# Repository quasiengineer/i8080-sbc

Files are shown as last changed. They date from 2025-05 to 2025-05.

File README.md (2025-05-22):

# System board for Intel 8080
FPGA-based single board computer to run Intel 8080 CPU (up to 3.125Mhz)

## Board

Full schematics in [pdf format](./pcb/schematic.pdf)

Here is shown only main part of the board:
schematic

Archive with gerber files and drill locations could be found [here](./pcb/manufacturing.zip)

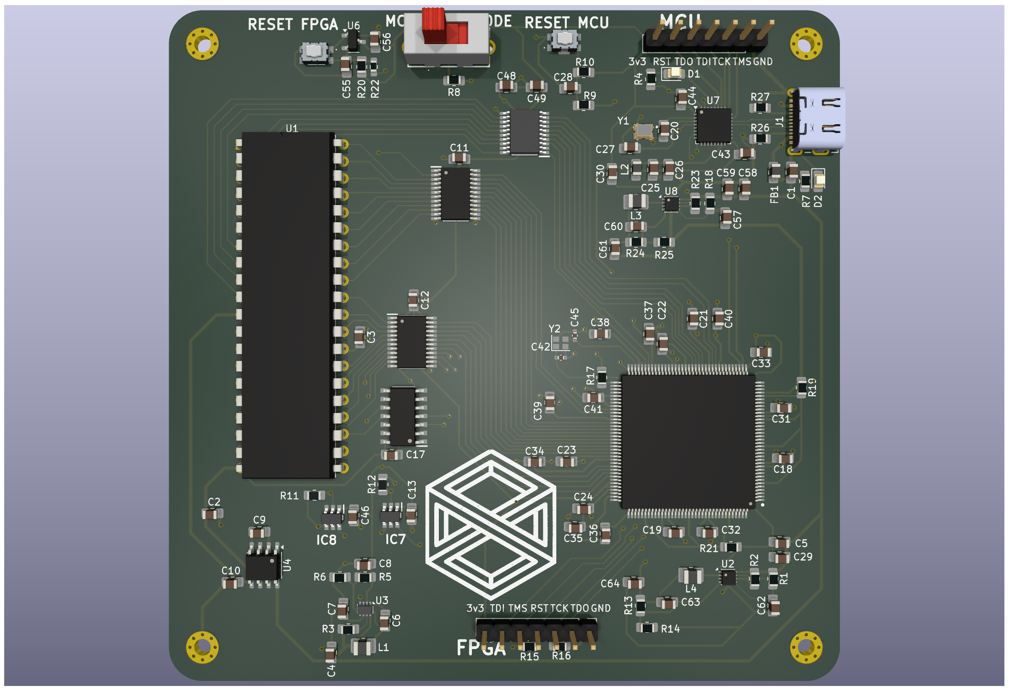
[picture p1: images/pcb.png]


Bill of material in [CSV format](./pcb/bom.csv)

|Reference |Value |Footprint |Mouser Part Number  |Qty|
|---|---|---|---|---|
|C1,C7,C25,C57,C62 |1u |Capacitor_SMD:C_0805_2012Metric_Pad1.18x1.45mm_HandSolder |187-CL21B105KAFNNNG |5  |
|C2,C3,C6,C11,C12,C13,C17,C18,C19,C21,C22,C23,<br>C24,C26,C28,C29,C31,C32,C33,C34,C35,C36,C37,<br>C38,C39,C40,C41,C43,C44,C46,C48,C49,C56,C58|100n |Capacitor_SMD:C_0805_2012Metric_Pad1.18x1.45mm_HandSolder |187-CL21B104KBCNNND |34 |
|C4,C30 |4u7,4u7, low-ESR |Capacitor_SMD:C_0805_2012Metric_Pad1.18x1.45mm_HandSolder |187-CL21A475KAQNNNE |2  |
|C5,C59,C61,C64 |22u |Capacitor_SMD:C_0805_2012Metric_Pad1.18x1.45mm_HandSolder |187-CL21A226MAYNNNE |4  |
|C8,C9,C10,C55 |10u,10u, low-ESR |Capacitor_SMD:C_0805_2012Metric_Pad1.18x1.45mm_HandSolder |187-CL21A106KAYNNNF |4  |
|C20,C27 |10p |Capacitor_SMD:C_0805_2012Metric_Pad1.18x1.45mm_HandSolder |710-885012007051 |2  |
|C42,C45 |10p |Capacitor_SMD:C_0402_1005Metric_Pad0.74x0.62mm_HandSolder |603-CC402JRNPO8BN100|2  |
|C60 |33p |Capacitor_SMD:C_0805_2012Metric_Pad1.18x1.45mm_HandSolder |710-885012007031 |1  |
|C63 |22p |Capacitor_SMD:C_0805_2012Metric_Pad1.18x1.45mm_HandSolder |710-885012007053 |1  |
|D1 |Red |LED_SMD:LED_0805_2012Metric_Pad1.15x1.40mm_HandSolder |710-150080RS75000 |1  |
|D2 |Green |LED_SMD:LED_0805_2012Metric_Pad1.15x1.40mm_HandSolder |710-150080GS75000 |1  |
|FB1 |Ferrite_Bead |Inductor_SMD:L_0805_2012Metric_Pad1.15x1.40mm_HandSolder  |652-MG2029-101Y |1  |
|H1,H2,H3,H4 |2.5mm |MountingHole:MountingHole_2.5mm_Pad_Via | |4  |
|IC1,IC2 |SN74LVC861APW |Project components:SOP65P640X120-24N |595-SN74LVC861APW |2  |
|IC5 |CD74HC243M96 |Project components:SOIC127P600X175-14N |595-CD74HC243M96 |1  |
|IC6 |M2GL005-TQG144I |Project components:QFP50P2200X2200X160-144N |494-M2GL005-TQG144I |1  |
|IC7,IC8 |UCC27511DBVR |SOT95P280X145-6N |595-UCC27511DBVR |2  |
|IC9 |TXS0108EPWRG4 |Project components:SOP65P640X120-20N |595-TXS0108EPWRG4 |1  |
|J1 |Type-C |Connector_USB:USB_C_Receptacle_JAE_DX07S016JA1R1500 |656-DX07S016JA1R1500|1  |
|J2,J4 |FPGA JTAG,MCU JTAG  |Connector_PinHeader_2.54mm:PinHeader_1x07_P2.54mm_Vertical|649-1012937990701BLF|2  |
|L1 |8u2, 800mA |Inductor_SMD:L_1008_2520Metric_Pad1.43x2.20mm_HandSolder  |81-DFE252012F-8R2MP2|1  |
|L2 |27n |Inductor_SMD:L_0805_2012Metric_Pad1.15x1.40mm_HandSolder  |652-CE201210-27NJ |1  |
|L3,L4 |0u68, 5.5A |Inductor_SMD:L_1008_2520Metric_Pad1.43x2.20mm_HandSolder  |652-SRP2512-R68M |2  |
|R1,R18 |10 |Resistor_SMD:R_0805_2012Metric_Pad1.20x1.40mm_HandSolder  |603-RT0805DRE0710RL |2  |
|R2,R13,R14,R23 |100k |Resistor_SMD:R_0805_2012Metric_Pad1.20x1.40mm_HandSolder  |603-RT0805DRE07100KL|4  |
|R3,R6 |30k |Resistor_SMD:R_0805_2012Metric_Pad1.20x1.40mm_HandSolder  |603-RT0805DRE0730KL |2  |
|R4 |4k7 |Resistor_SMD:R_0805_2012Metric_Pad1.20x1.40mm_HandSolder  |603-RT0805FRE134K7L |1  |
|R5 |330k |Resistor_SMD:R_0805_2012Metric_Pad1.20x1.40mm_HandSolder  |603-RT0805FRE07330KL|1  |
|R7 |2k2 |Resistor_SMD:R_0805_2012Metric_Pad1.20x1.40mm_HandSolder  |603-RT0805FRE072K2L |1  |
|R8,R10,R19,R20,R21 |10k |Resistor_SMD:R_0805_2012Metric_Pad1.20x1.40mm_HandSolder  |603-RT0805DRD0710KL |5  |
|R9,R11,R12 |220 |Resistor_SMD:R_0805_2012Metric_Pad1.20x1.40mm_HandSolder  |603-RT0805FRE07220RL|3  |
|R15,R16,R17 |1k |Resistor_SMD:R_0805_2012Metric_Pad1.20x1.40mm_HandSolder  |603-RT0805FRE071KL  |3  |
|R22 |50 |Resistor_SMD:R_0603_1608Metric_Pad0.98x0.95mm_HandSolder  |603-RT0603BRE0750RL |1  |
|R24 |158k |Resistor_SMD:R_0805_2012Metric_Pad1.20x1.40mm_HandSolder  |603-RT0805FRE07158KL|1  |
|R25 |34k8 |Resistor_SMD:R_0805_2012Metric_Pad1.20x1.40mm_HandSolder  |603-RT0805FRE0734K8L|1  |
|R26,R27 |5k1 |Resistor_SMD:R_0805_2012Metric_Pad1.20x1.40mm_HandSolder  |603-RT0805FRE075K1L |2  |
|SW1 |BOOT_MODE |Project components:SLW1215865AD |SLW-121586-5A-D |1  |
|SW2,SW3 |RESET_FPGA,RESET_MCU|Project components:435451019820 |710-435451019820 |2  |
|U1 |8080A |Package_DIP:DIP-40_W15.24mm |571-1-2199299-5 |1  |
|U2,U8 |LX7167ACLD-TR |Package_DFN_QFN:DFN-8-1EP_2x2mm_P0.5mm_EP0.8x1.6mm |494-LX7167ACLD-TR |2  |
|U3 |MP3438 |Package_TO_SOT_SMD:SOT-583-8 |946-MP3438GTL-P |1  |
|U4 |ICL7660 |Package_SO:SOIC-8_3.9x4.9mm_P1.27mm |968-ICL7660CBAZA-T  |1  |
|U6 |APX803-31SAG-7 |Package_TO_SOT_SMD:SOT-23-3 |621-APX803-31SAG-7  |1  |
|U7 |STM32G4A1KEUx |Package_DFN_QFN:QFN-32-1EP_5x5mm_P0.5mm_EP3.45x3.45mm |511-STM32G4A1KEU6 |1  |
|Y1 |16Mhz, CL=10p |Project components:XTAL_ECS-160-10-36-CKM-TR3 |520-160-10-36CKM-TR3|1  |
|Y2 |16Mhz |Crystal:Crystal_SMD_2016-4Pin_2.0x1.6mm |81-XRCGB16M000FXN02R|1  |

## MCU Firmware

There is compiled [hex file](./firmware/bin/i8080-sbc.hex) in repository, that could be flashed to PCB.

To flash you can use your favorite JTAG probe and software by your choice.
Or you can use default stm32 bootloader that supports uploading firmware via USB - just switch BOOT switch in direction to the USB connector.

I am using ft232r-based probe and OpenOCD, you can find my config [here](./openocd_stm32.cfg).

## FPGA bitstream

Again there is compiled [bitsream](./fpga/bin/i8080-sbc.dat).
So you could flash it by using either tool from vendor like FlashPro programmer or use same ft232 board and [DirectC-based tool](https://github.com/quasiengineer/microchip-jtag-flasher-ftdi).

## Software

To upload ROM/RAM image (i8080 has same memory space for ROM and RAM) you can type:

```sh
node index.js -port="COM1" -rom="hello_world" -verify
```

If all is good terminal should looks like that:

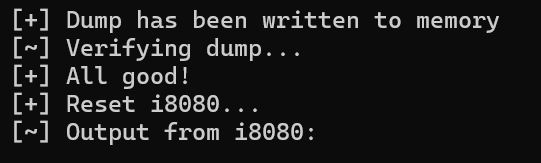
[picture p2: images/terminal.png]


Be aware that FPGA currently does not inform about i8080 HALT state, so controller software need to be terminated after end of i8080 program execution.

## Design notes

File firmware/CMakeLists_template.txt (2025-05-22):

#${templateWarning}
set(CMAKE_SYSTEM_NAME Generic)
set(CMAKE_SYSTEM_VERSION 1)
${cmakeRequiredVersion}
# specify cross-compilers and tools
set(CMAKE_C_COMPILER arm-none-eabi-gcc)
set(CMAKE_CXX_COMPILER arm-none-eabi-g++)
set(CMAKE_ASM_COMPILER  arm-none-eabi-gcc)
set(CMAKE_AR arm-none-eabi-ar)
set(CMAKE_OBJCOPY arm-none-eabi-objcopy)
set(CMAKE_OBJDUMP arm-none-eabi-objdump)
set(SIZE arm-none-eabi-size)
set(CMAKE_TRY_COMPILE_TARGET_TYPE STATIC_LIBRARY)

# project settings
project(${projectName} C CXX ASM)
set(CMAKE_CXX_STANDARD 17)
set(CMAKE_C_STANDARD 11)

#Uncomment for hardware floating point
#add_compile_definitions(ARM_MATH_CM4;ARM_MATH_MATRIX_CHECK;ARM_MATH_ROUNDING)
#add_compile_options(-mfloat-abi=hard -mfpu=fpv4-sp-d16)
#add_link_options(-mfloat-abi=hard -mfpu=fpv4-sp-d16)

#Uncomment for software floating point
#add_compile_options(-mfloat-abi=soft)

add_compile_options(-mcpu=${mcpu} -mthumb -mthumb-interwork)
add_compile_options(-ffunction-sections -fdata-sections -fno-common -fmessage-length=0)

# uncomment to mitigate c++17 absolute addresses warnings
#set(CMAKE_CXX_FLAGS "$${CMAKE_CXX_FLAGS} -Wno-register")

# Enable assembler files preprocessing
add_compile_options($<$<COMPILE_LANGUAGE:ASM>:-x$<SEMICOLON>assembler-with-cpp>)

if ("$${CMAKE_BUILD_TYPE}" STREQUAL "Release")
    message(STATUS "Maximum optimization for speed")
    add_compile_options(-Ofast)
elseif ("$${CMAKE_BUILD_TYPE}" STREQUAL "RelWithDebInfo")
    message(STATUS "Maximum optimization for speed, debug info included")
    add_compile_options(-Ofast -g)
elseif ("$${CMAKE_BUILD_TYPE}" STREQUAL "MinSizeRel")
    message(STATUS "Maximum optimization for size")
    add_compile_options(-Os)
else ()
    message(STATUS "Minimal optimization, debug info included")
    add_compile_options(-Og -g)
endif ()

include_directories(${includes} App)

add_definitions(${defines})

file(GLOB_RECURSE SOURCES ${sources} "App/*.*")

set(LINKER_SCRIPT $${CMAKE_SOURCE_DIR}/${linkerScript})

add_link_options(-Wl,-gc-sections,--print-memory-usage,-Map=$${PROJECT_BINARY_DIR}/$${PROJECT_NAME}.map)
add_link_options(-mcpu=${mcpu} -mthumb -mthumb-interwork)
add_link_options(-T $${LINKER_SCRIPT})

add_executable($${PROJECT_NAME}.elf $${SOURCES} $${LINKER_SCRIPT})

set(HEX_FILE $${PROJECT_BINARY_DIR}/$${PROJECT_NAME}.hex)
set(BIN_FILE $${PROJECT_BINARY_DIR}/$${PROJECT_NAME}.bin)

add_custom_command(TARGET $${PROJECT_NAME}.elf POST_BUILD
        COMMAND $${CMAKE_OBJCOPY} -Oihex $<TARGET_FILE:$${PROJECT_NAME}.elf> $${HEX_FILE}
        COMMAND $${CMAKE_OBJCOPY} -Obinary $<TARGET_FILE:$${PROJECT_NAME}.elf> $${BIN_FILE}
        COMMENT "Building $${HEX_FILE}
Building $${BIN_FILE}")

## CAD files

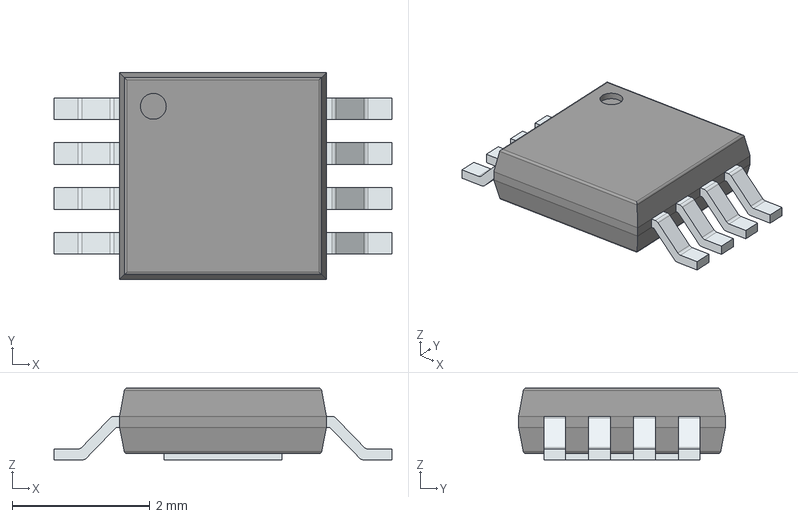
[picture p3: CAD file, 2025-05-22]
pcb/components/3d/2EDN7524RXTMA1.stp
4.90 x 3.00 x 1.04 mm
PinsArrayLR
ThermalPad

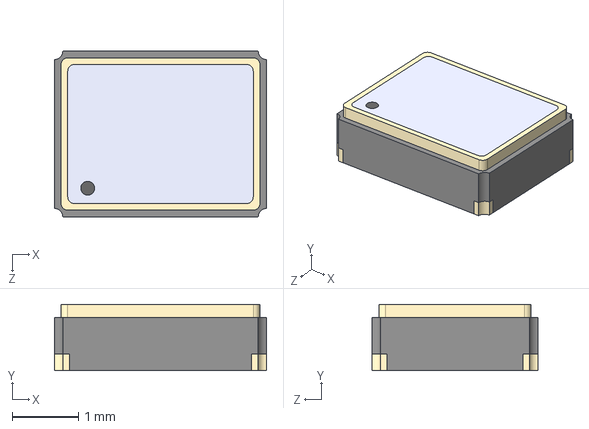
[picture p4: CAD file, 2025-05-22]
pcb/components/3d/ECS-2333-100-BN-TR.step
3.20 x 1.00 x 2.50 mm

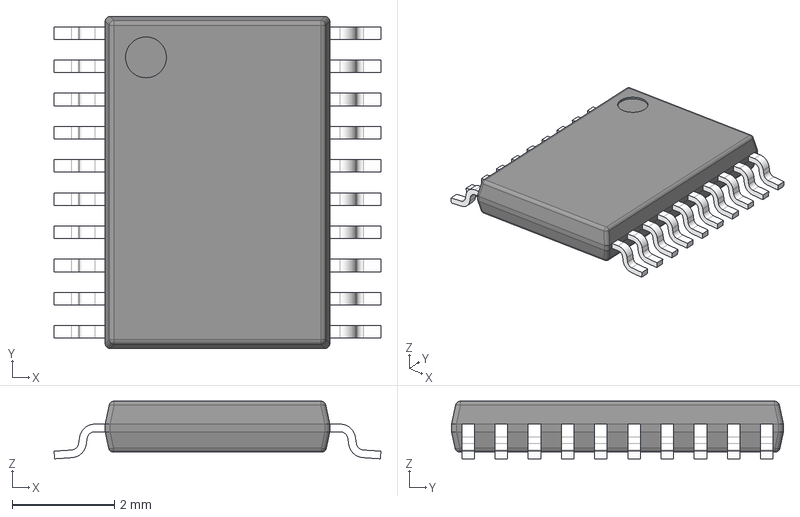
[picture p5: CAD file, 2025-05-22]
pcb/components/3d/TXS0108EPWRG4.stp
6.40 x 6.50 x 1.13 mm
BODY-TSSOP
LEAD-TSSOP x 20
PIN1

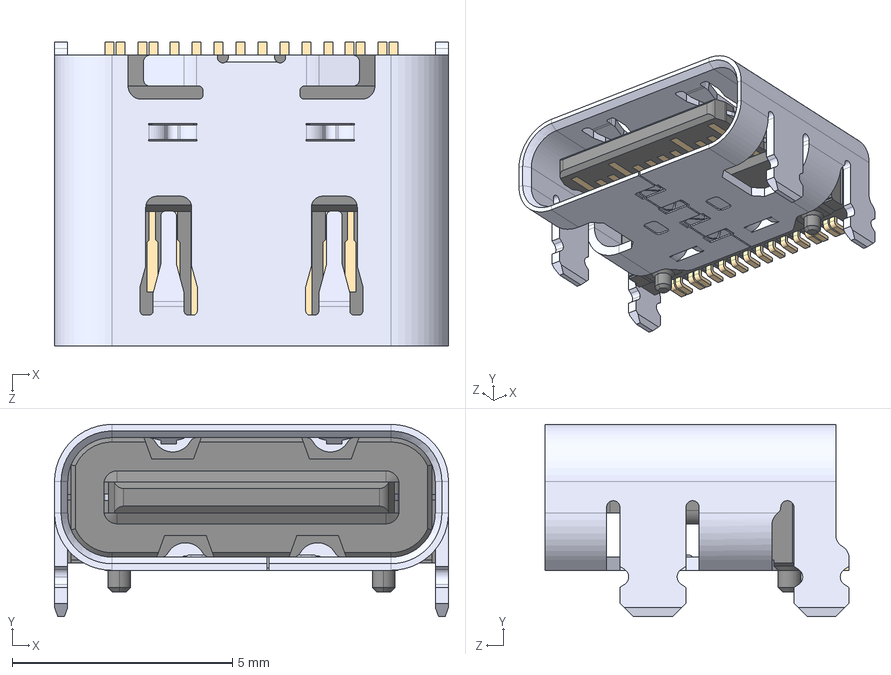
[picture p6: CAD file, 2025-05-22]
pcb/components/3d/DX07S016JA1R1500.stp
8.94 x 4.36 x 6.90 mm

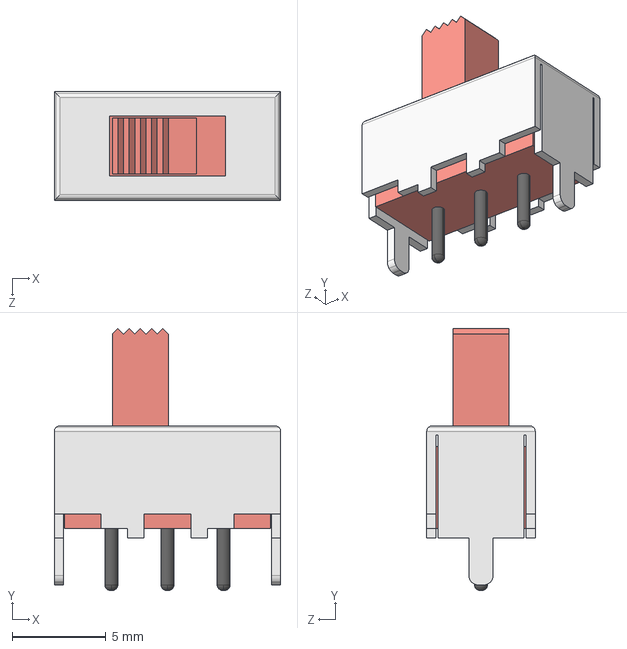
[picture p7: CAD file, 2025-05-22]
pcb/components/3d/SLW-121586-5A-D.STEP
12.1 x 14.0 x 5.80 mm

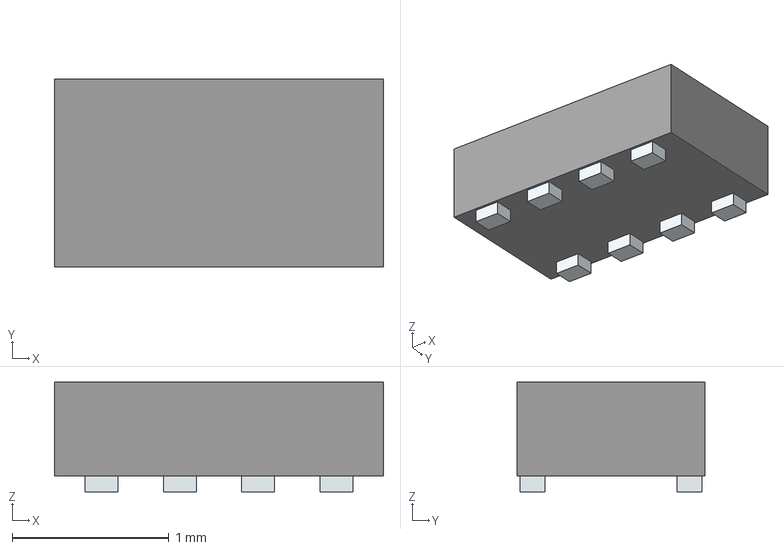
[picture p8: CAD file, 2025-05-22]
pcb/components/3d/MP3438GTL-P.stp
2.10 x 1.20 x 0.7 mm
Pins

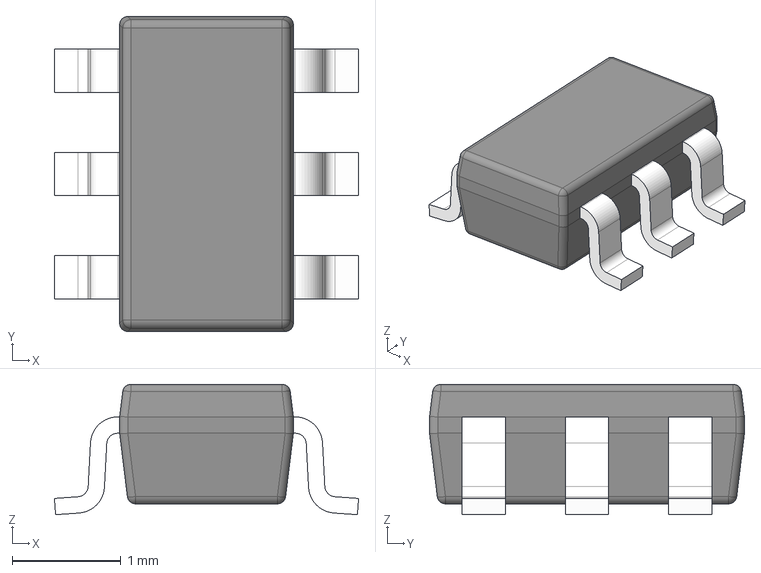
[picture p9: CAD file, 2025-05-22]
pcb/components/3d/UCC27511DBVR.stp
2.80 x 2.90 x 1.20 mm
BODY-SOT
LEAD-SOT x 6

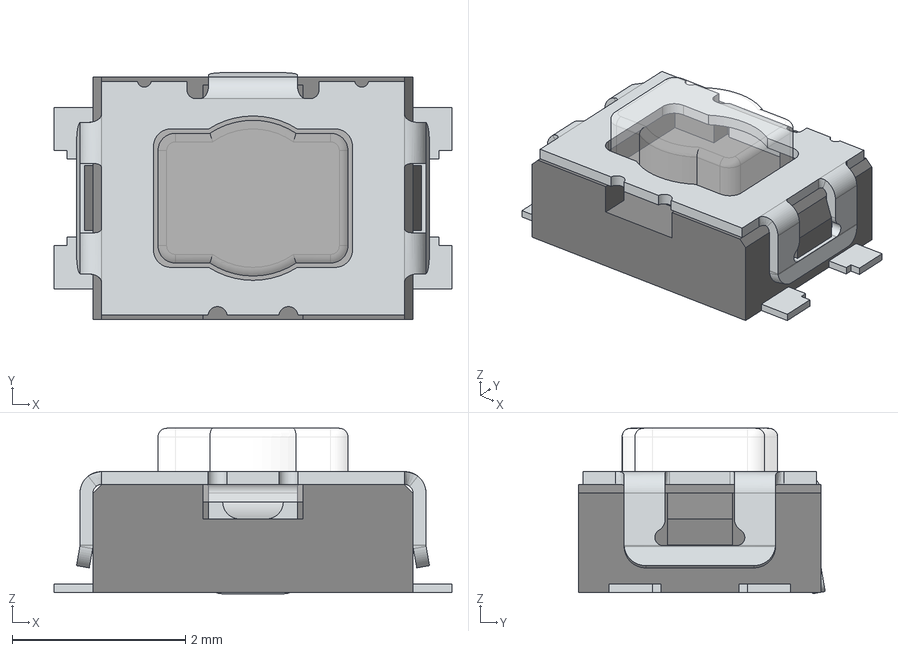
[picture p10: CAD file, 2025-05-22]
pcb/components/3d/435451019820.stp
4.60 x 2.85 x 1.91 mm
Frame
Cover
Terminal
Button

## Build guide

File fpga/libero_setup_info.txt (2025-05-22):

# Microsemi Corp.
# Date: 2025-May-22 11:26:16
Libero Release : v2024.1
Libero Version : 2024.1.0.3
Operating System Name : Windows 8
Ram Size : 127.71 GB (usable)
OS Type : 64-bit

Environment Variables : 
---------------------
	Please enable the option from 'Preferences => Startup => Export environment variables' to get this info.

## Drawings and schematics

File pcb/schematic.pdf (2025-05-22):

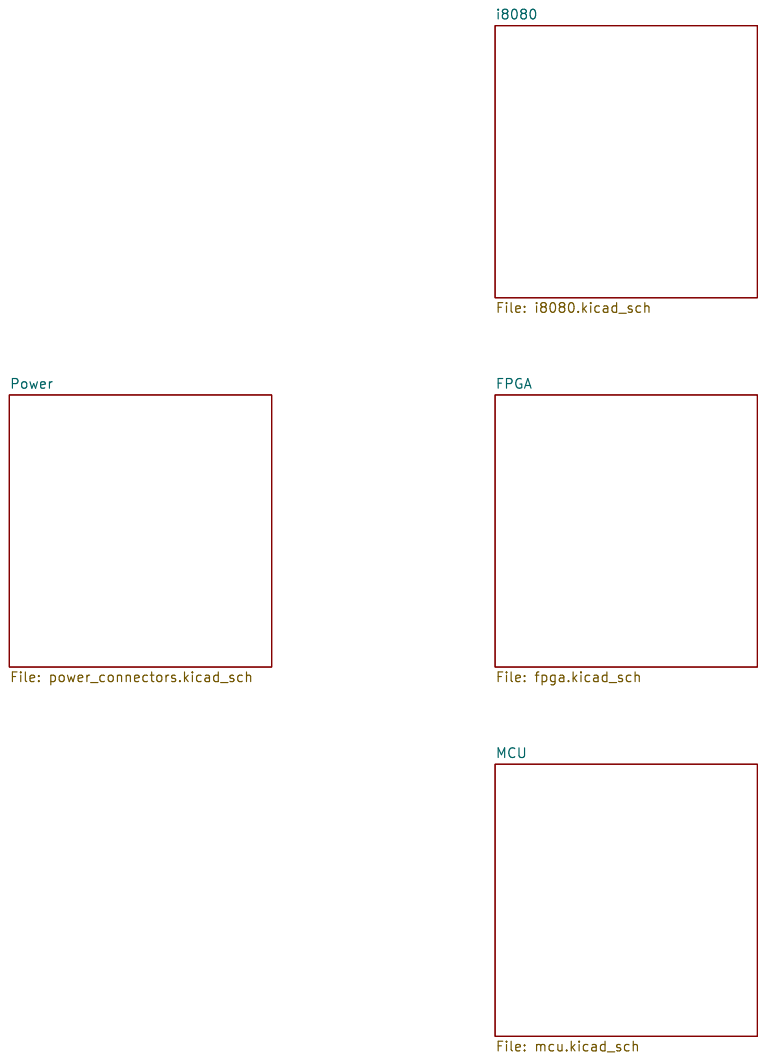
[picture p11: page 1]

Id: 1/5 Title: File: i8080-sbc.kicad_sch Sheet: /

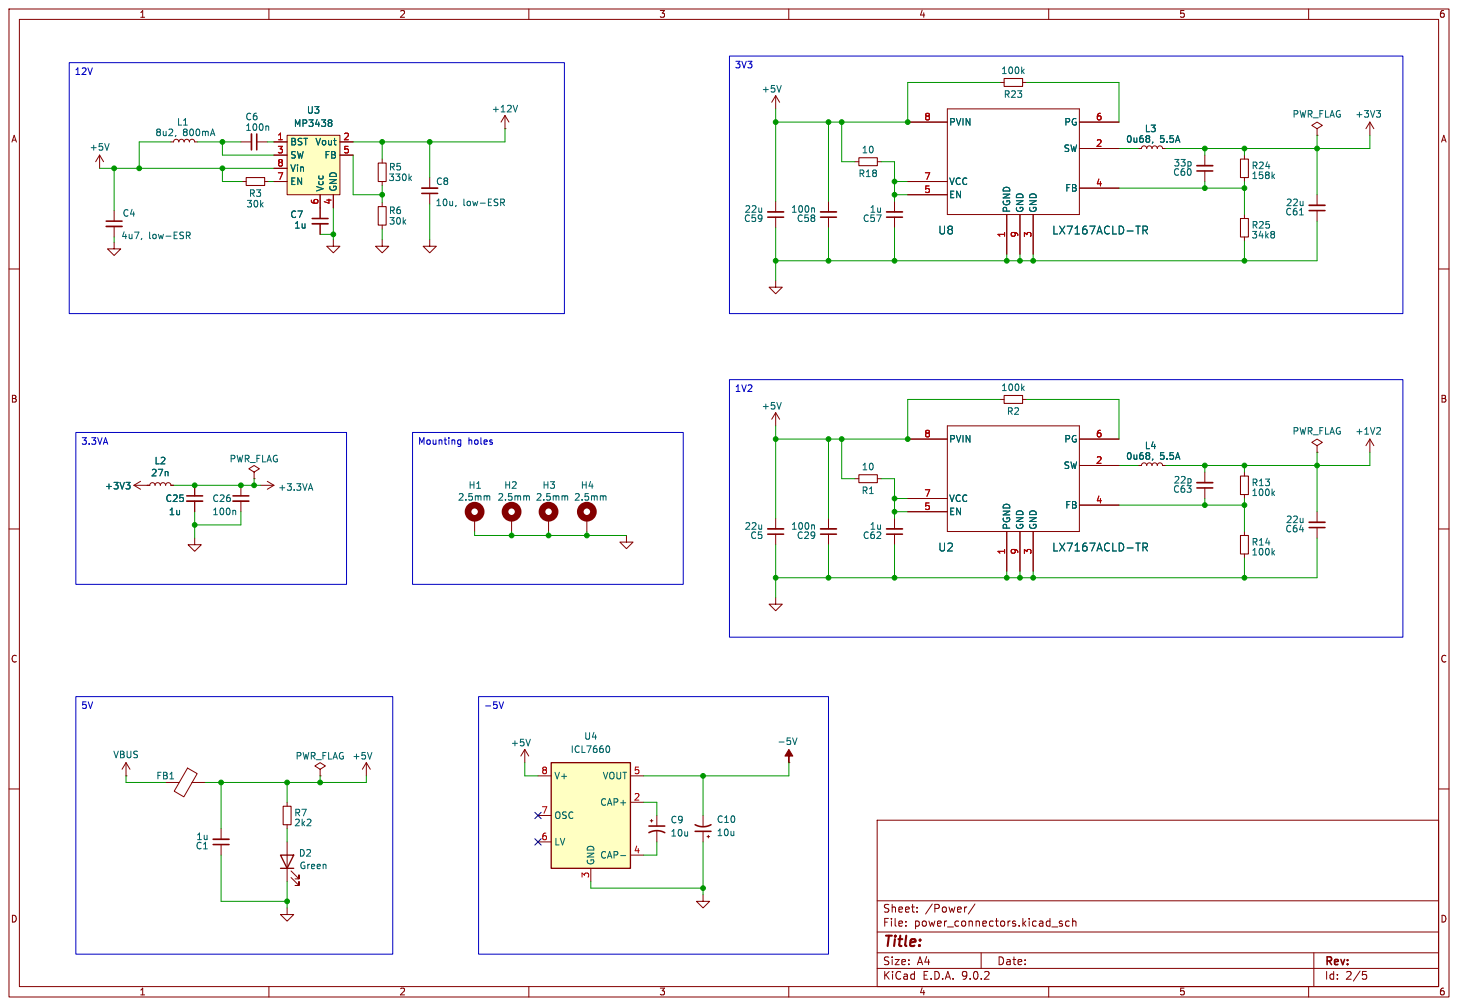
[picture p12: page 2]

3 PG 6 SW 2 FB 4 U8 LX7167ACLD-TR

3 PG 6 SW 2 FB 4 U2 LX7167ACLD-TR

Id: 2/5 Title: File: power_connectors.kicad_sch Sheet: /Power/ C1

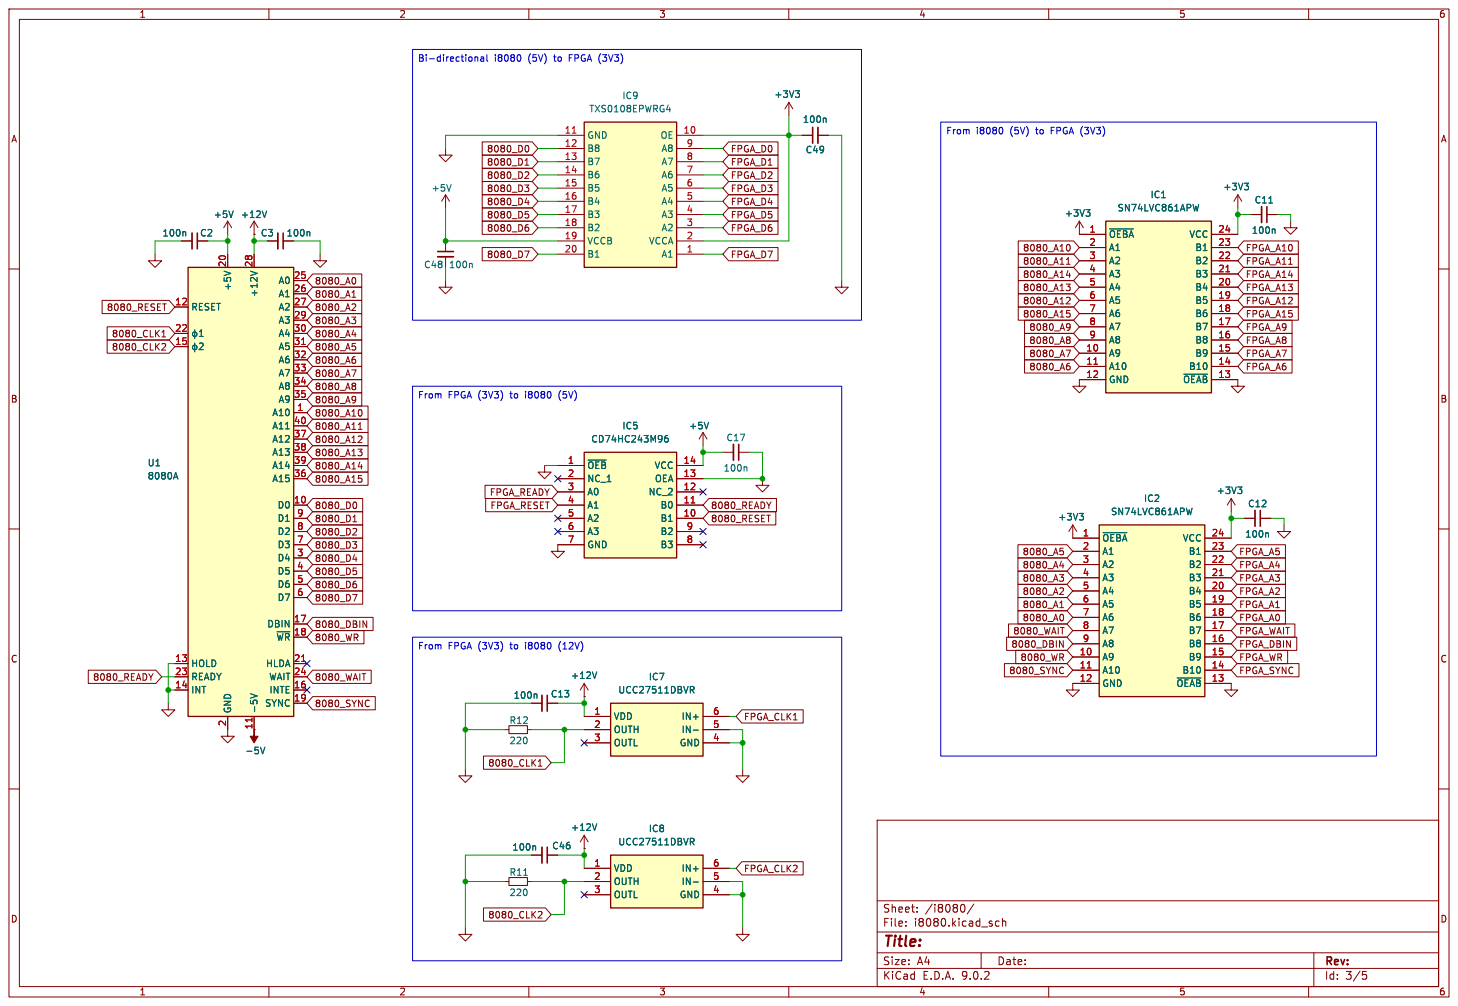
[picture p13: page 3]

Id: 3/5 Title: File: i8080.kicad_sch Sheet: /i8080/

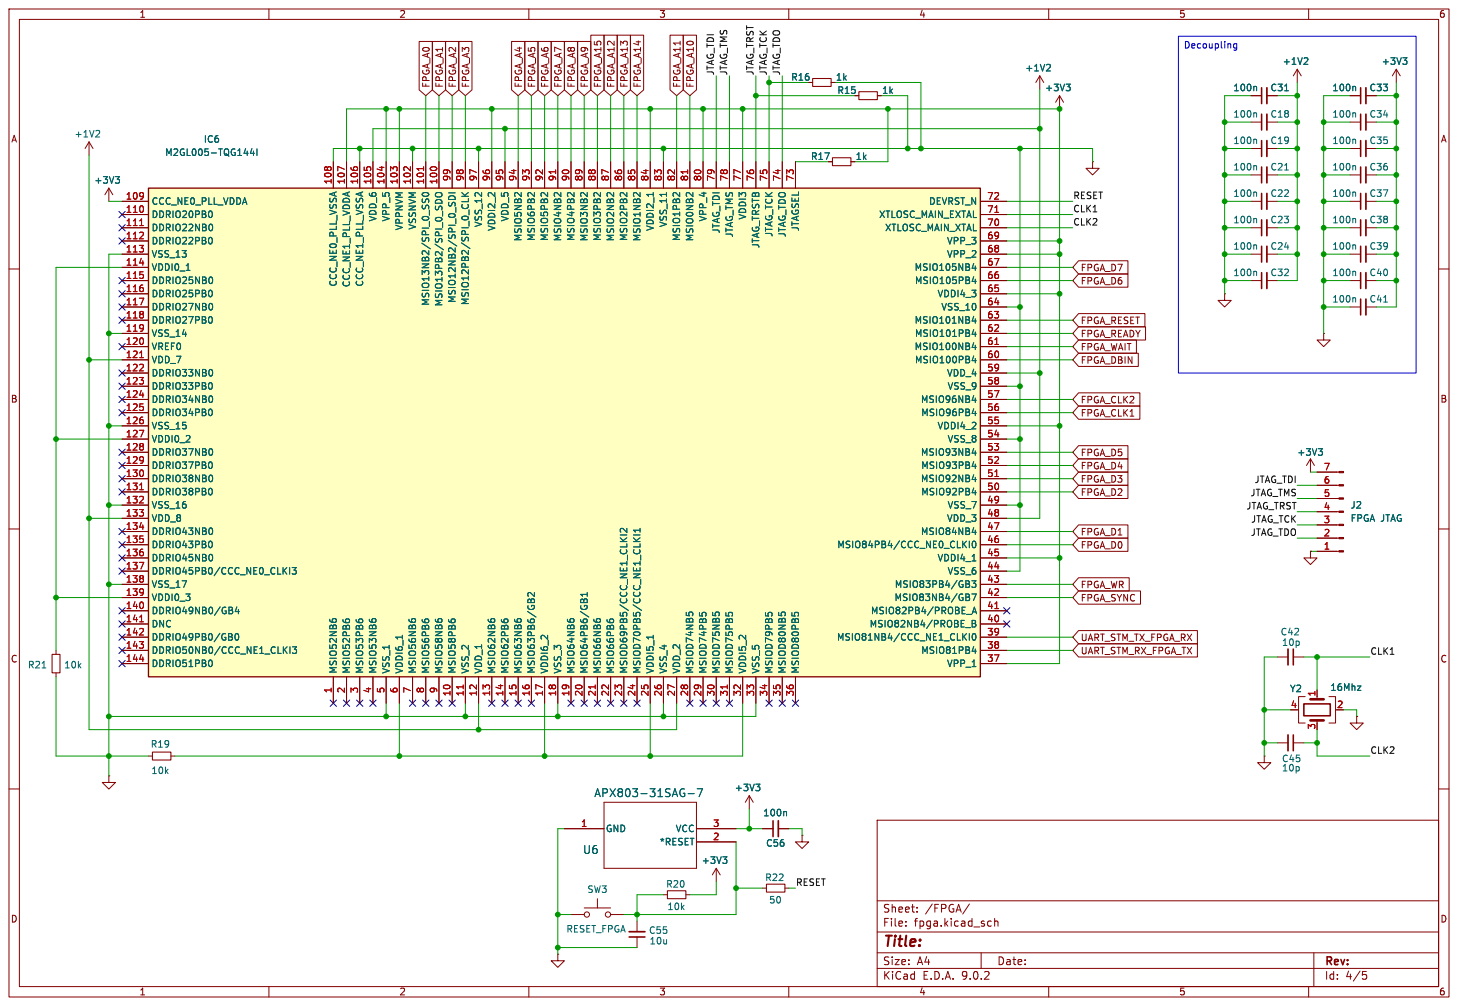
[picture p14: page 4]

Id: 4/5 Title: File: fpga.kicad_sch Sheet: /FPGA/

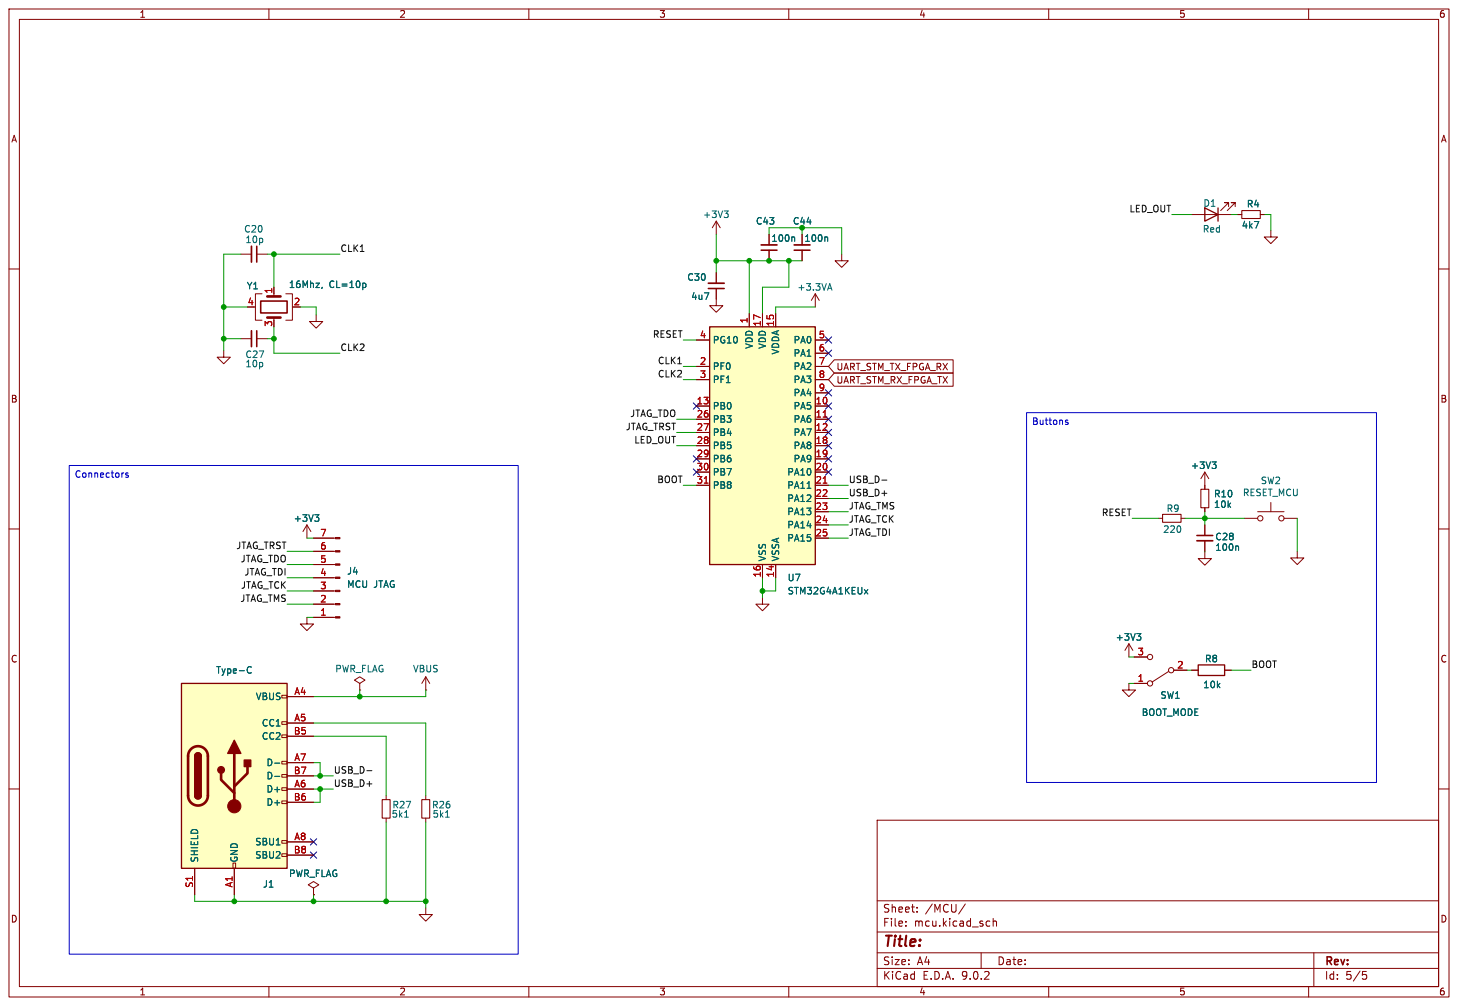
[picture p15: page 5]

1 VDD 17 VSS 16 VDDA 15 VSSA 14 PA0 5 PA1 6 PA2 7 PA3 8 PA4 9 PA5 10 PA6 11 PA7 12 PA8 18 PA9 19 PA10 20 PA11 21 PA12 22 PA13 23 PA14 24 PA15 25 U7STM32G4A1KEUx R10

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

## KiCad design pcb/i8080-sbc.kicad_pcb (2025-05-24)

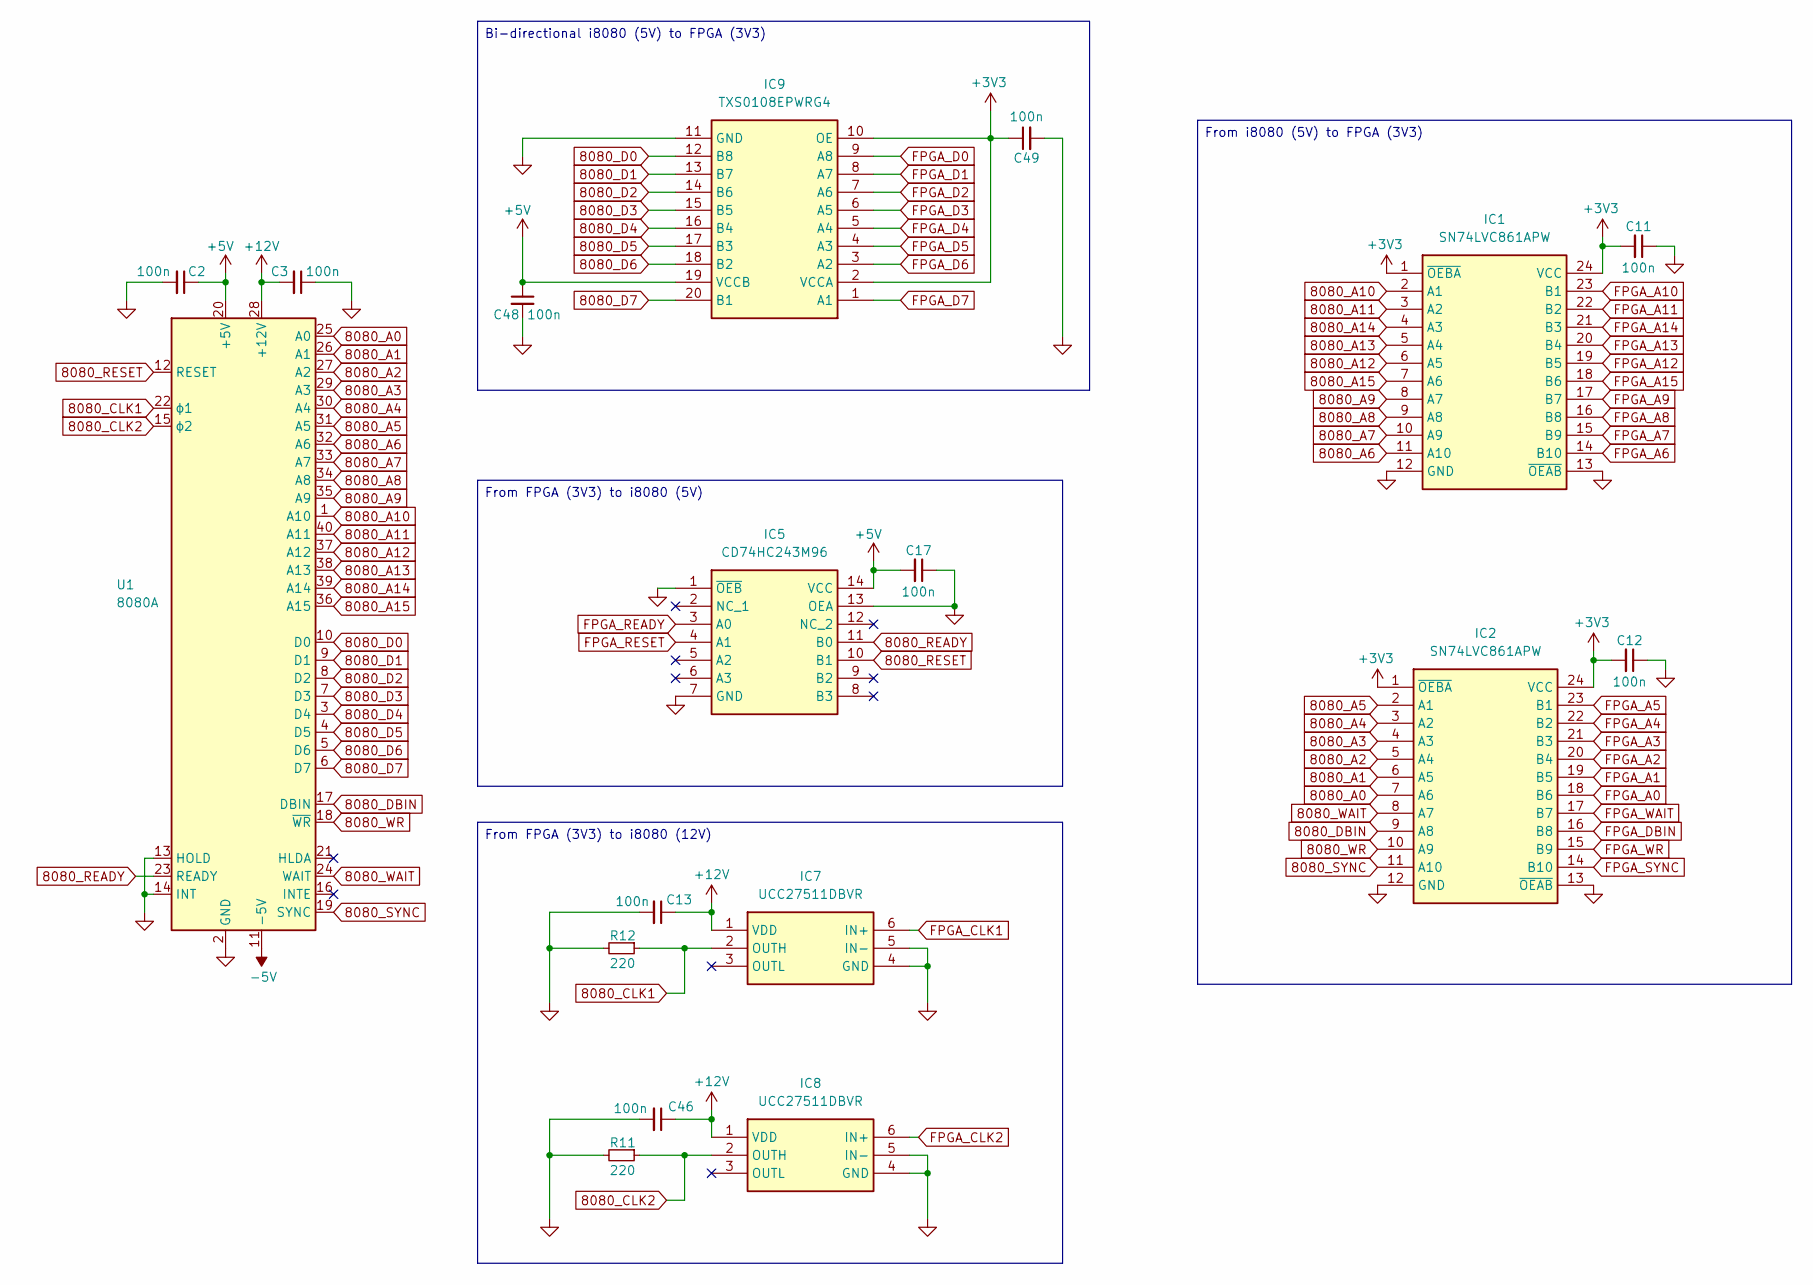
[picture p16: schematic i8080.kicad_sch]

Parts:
C2, C3, C11, C12, C13, C17, C46, C48, C49: 100n; C_0805_2012Metric_Pad1.18x1.45mm_HandSolder; Mouser Part Number 187-CL21B104KBCNNND
IC1, IC2: SN74LVC861APW; SOP65P640X120-24N; Mouser Part Number 595-SN74LVC861APW
IC5: CD74HC243M96; SOIC127P600X175-14N; Mouser Part Number 595-CD74HC243M96
IC7, IC8: UCC27511DBVR; SOT95P280X145-6N; Mouser Part Number 595-UCC27511DBVR
IC9: TXS0108EPWRG4; SOP65P640X120-20N; Mouser Part Number 595-TXS0108EPWRG4
R11, R12: 220; R_0805_2012Metric_Pad1.20x1.40mm_HandSolder; Mouser Part Number 603-RT0805FRE07220RL
U1: 8080A; DIP-40_W15.24mm; Mouser Part Number 571-1-2199299-5

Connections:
8080_A0: IC2.7 (A6), U1.25 (A0)
8080_A1: IC2.6 (A5), U1.26 (A1)
8080_A2: IC2.5 (A4), U1.27 (A2)
8080_A3: IC2.4 (A3), U1.29 (A3)
8080_A4: IC2.3 (A2), U1.30 (A4)
8080_A5: IC2.2 (A1), U1.31 (A5)
8080_A6: IC1.11 (A10), U1.32 (A6)
8080_A7: IC1.10 (A9), U1.33 (A7)
8080_A8: IC1.9 (A8), U1.34 (A8)
8080_A9: IC1.8 (A7), U1.35 (A9)
8080_A10: IC1.2 (A1), U1.1 (A10)
8080_A11: IC1.3 (A2), U1.40 (A11)
8080_A12: IC1.6 (A5), U1.37 (A12)
8080_A13: IC1.5 (A4), U1.38 (A13)
8080_A14: IC1.4 (A3), U1.39 (A14)
8080_A15: IC1.7 (A6), U1.36 (A15)
8080_CLK1: IC7.2 (OUTH), R12.1, U1.22 (ϕ1)
8080_CLK2: IC8.2 (OUTH), R11.1, U1.15 (ϕ2)
8080_D0: IC9.12 (B8), U1.10 (D0)
8080_D1: IC9.13 (B7), U1.9 (D1)
8080_D2: IC9.14 (B6), U1.8 (D2)
8080_D3: IC9.15 (B5), U1.7 (D3)
8080_D4: IC9.16 (B4), U1.3 (D4)
8080_D5: IC9.17 (B3), U1.4 (D5)
8080_D6: IC9.18 (B2), U1.5 (D6)
8080_D7: IC9.20 (B1), U1.6 (D7)
8080_DBIN: IC2.9 (A8), U1.17 (DBIN)
8080_READY: IC5.11 (B0), U1.23 (READY)
8080_RESET: IC5.10 (B1), U1.12 (RESET)
8080_SYNC: IC2.11 (A10), U1.19 (SYNC)
8080_WAIT: IC2.8 (A7), U1.24 (WAIT)
8080_WR: IC2.10 (A9), U1.18 (~WR)
+3V3: C11.2, C12.2, C49.1, IC1.1 (~OEBA), IC1.24 (VCC), IC2.1 (~OEBA), IC2.24 (VCC), IC9.2 (VCCA), IC9.10 (OE); also elsewhere on the board
+5V: C2.1, C17.2, C48.1, IC5.14 (VCC), IC9.19 (VCCB), U1.20 (+5V); also elsewhere on the board
+12V: C3.2, C13.1, C46.1, IC7.1 (VDD), IC8.1 (VDD), U1.28 (+12V); also elsewhere on the board
-5V: U1.11 (-5V); also elsewhere on the board
FPGA_A0: IC2.18 (B6); also elsewhere on the board
FPGA_A1: IC2.19 (B5); also elsewhere on the board
FPGA_A2: IC2.20 (B4); also elsewhere on the board
FPGA_A3: IC2.21 (B3); also elsewhere on the board
FPGA_A4: IC2.22 (B2); also elsewhere on the board
FPGA_A5: IC2.23 (B1); also elsewhere on the board
FPGA_A6: IC1.14 (B10); also elsewhere on the board
FPGA_A7: IC1.15 (B9); also elsewhere on the board
FPGA_A8: IC1.16 (B8); also elsewhere on the board
FPGA_A9: IC1.17 (B7); also elsewhere on the board
FPGA_A10: IC1.23 (B1); also elsewhere on the board
FPGA_A11: IC1.22 (B2); also elsewhere on the board
FPGA_A12: IC1.19 (B5); also elsewhere on the board
FPGA_A13: IC1.20 (B4); also elsewhere on the board
FPGA_A14: IC1.21 (B3); also elsewhere on the board
FPGA_A15: IC1.18 (B6); also elsewhere on the board
FPGA_CLK1: IC7.6 (IN+); also elsewhere on the board
FPGA_CLK2: IC8.6 (IN+); also elsewhere on the board
FPGA_D0: IC9.9 (A8); also elsewhere on the board
FPGA_D1: IC9.8 (A7); also elsewhere on the board
FPGA_D2: IC9.7 (A6); also elsewhere on the board
FPGA_D3: IC9.6 (A5); also elsewhere on the board
FPGA_D4: IC9.5 (A4); also elsewhere on the board
FPGA_D5: IC9.4 (A3); also elsewhere on the board
FPGA_D6: IC9.3 (A2); also elsewhere on the board
FPGA_D7: IC9.1 (A1); also elsewhere on the board
FPGA_DBIN: IC2.16 (B8); also elsewhere on the board
FPGA_READY: IC5.3 (A0); also elsewhere on the board
FPGA_RESET: IC5.4 (A1); also elsewhere on the board
FPGA_SYNC: IC2.14 (B10); also elsewhere on the board
FPGA_WAIT: IC2.17 (B7); also elsewhere on the board
FPGA_WR: IC2.15 (B9); also elsewhere on the board
GND: C2.2, C3.1, C11.1, C12.1, C13.2, C17.1, C46.2, C48.2, C49.2, IC1.12 (GND), IC1.13 (~OEAB), IC2.12 (GND), IC2.13 (~OEAB), IC5.1 (~OEB), IC5.7 (GND), IC5.13 (OEA), IC7.4 (GND), IC7.5 (IN-), IC8.4 (GND), IC8.5 (IN-), IC9.11 (GND), R11.2, R12.2, U1.2 (GND), U1.13 (HOLD), U1.14 (INT); also elsewhere on the board

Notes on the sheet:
From FPGA (3V3) to i8080 (12V)
From i8080 (5V) to FPGA (3V3)
Bi-directional i8080 (5V) to FPGA (3V3)
From FPGA (3V3) to i8080 (5V)

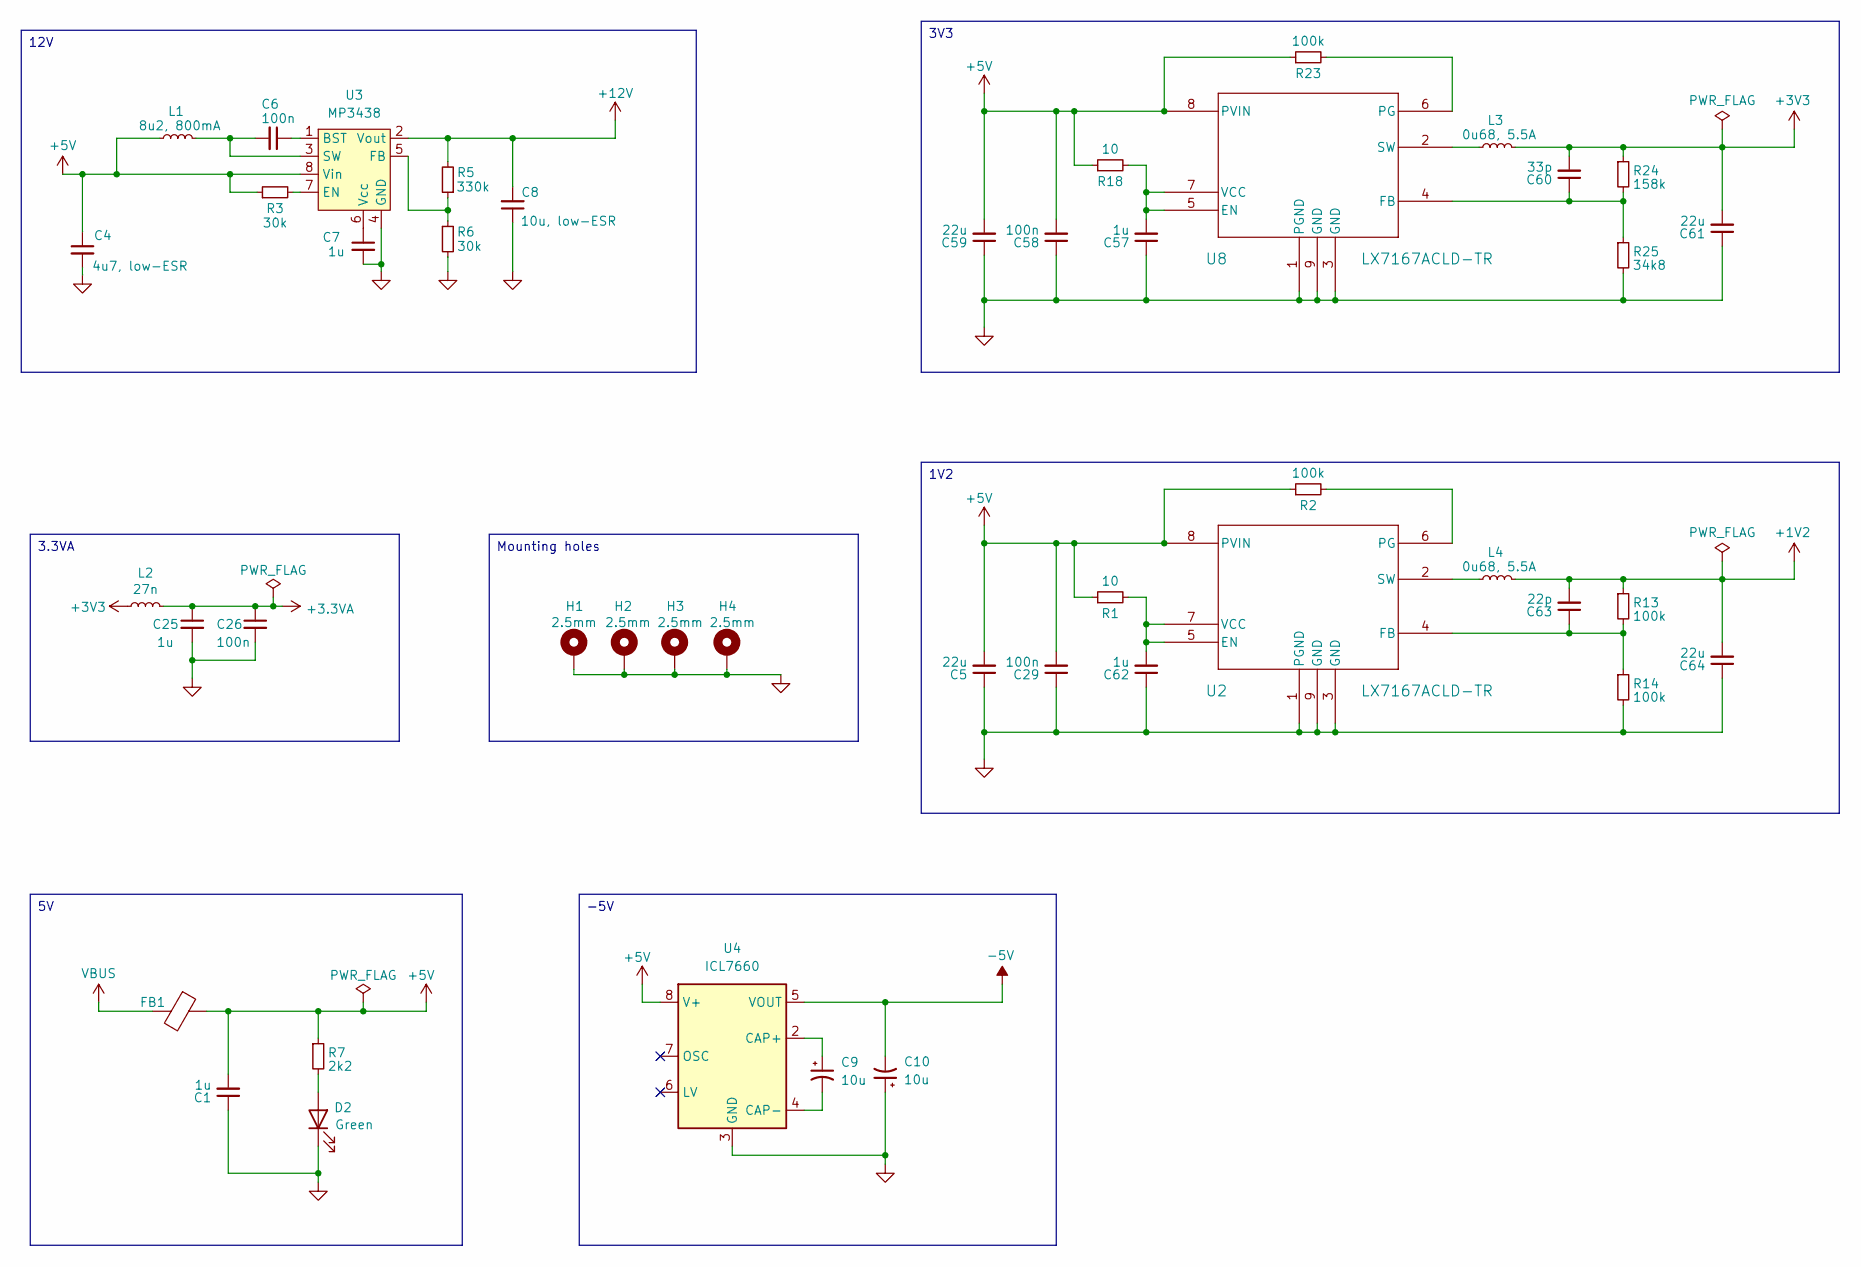
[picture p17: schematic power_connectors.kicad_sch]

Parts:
C1, C7, C25, C57, C62: 1u; C_0805_2012Metric_Pad1.18x1.45mm_HandSolder; Mouser Part Number 187-CL21B105KAFNNNG
C4: 4u7, low-ESR; C_0805_2012Metric_Pad1.18x1.45mm_HandSolder; Mouser Part Number 187-CL21A475KAQNNNE
C5, C59, C61, C64: 22u; C_0805_2012Metric_Pad1.18x1.45mm_HandSolder; Mouser Part Number 187-CL21A226MAYNNNE
C6, C26, C29, C58: 100n; C_0805_2012Metric_Pad1.18x1.45mm_HandSolder; Mouser Part Number 187-CL21B104KBCNNND
C8: 10u, low-ESR; C_0805_2012Metric_Pad1.18x1.45mm_HandSolder; Mouser Part Number 187-CL21A106KAYNNNF
C9, C10: 10u; C_0805_2012Metric_Pad1.18x1.45mm_HandSolder; Mouser Part Number 187-CL21A106KAYNNNF
C60: 33p; C_0805_2012Metric_Pad1.18x1.45mm_HandSolder; Mouser Part Number 710-885012007031
C63: 22p; C_0805_2012Metric_Pad1.18x1.45mm_HandSolder; Mouser Part Number 710-885012007053
D2: Green; LED_0805_2012Metric_Pad1.15x1.40mm_HandSolder; Mouser Part Number 710-150080GS75000
FB1: Ferrite_Bead; L_0805_2012Metric_Pad1.15x1.40mm_HandSolder; Mouser Part Number 652-MG2029-101Y
H1, H2, H3, H4: 2.5mm; MountingHole_2.5mm_Pad_Via
L1: 8u2, 800mA; L_1008_2520Metric_Pad1.43x2.20mm_HandSolder; Mouser Part Number 81-DFE252012F-8R2MP2
L2: 27n; L_0805_2012Metric_Pad1.15x1.40mm_HandSolder; Mouser Part Number 652-CE201210-27NJ
L3, L4: 0u68, 5.5A; L_1008_2520Metric_Pad1.43x2.20mm_HandSolder; Mouser Part Number 652-SRP2512-R68M
R1, R18: 10; R_0805_2012Metric_Pad1.20x1.40mm_HandSolder; Mouser Part Number 603-RT0805DRE0710RL
R2, R13, R14, R23: 100k; R_0805_2012Metric_Pad1.20x1.40mm_HandSolder; Mouser Part Number 603-RT0805DRE07100KL
R3, R6: 30k; R_0805_2012Metric_Pad1.20x1.40mm_HandSolder; Mouser Part Number 603-RT0805DRE0730KL
R5: 330k; R_0805_2012Metric_Pad1.20x1.40mm_HandSolder; Mouser Part Number 603-RT0805FRE07330KL
R7: 2k2; R_0805_2012Metric_Pad1.20x1.40mm_HandSolder; Mouser Part Number 603-RT0805FRE072K2L
R24: 158k; R_0805_2012Metric_Pad1.20x1.40mm_HandSolder; Mouser Part Number 603-RT0805FRE07158KL
R25: 34k8; R_0805_2012Metric_Pad1.20x1.40mm_HandSolder; Mouser Part Number 603-RT0805FRE0734K8L
U2, U8: LX7167ACLD-TR; DFN-8-1EP_2x2mm_P0.5mm_EP0.8x1.6mm; Mouser Part Number 494-LX7167ACLD-TR
U3: MP3438; SOT-583-8; Mouser Part Number 946-MP3438GTL-P
U4: ICL7660; SOIC-8_3.9x4.9mm_P1.27mm; Mouser Part Number 968-ICL7660CBAZA-T

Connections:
+1V2: C63.2, C64.2, L4.2, R13.1; also elsewhere on the board
+3.3VA: C25.1, C26.1, L2.2; also elsewhere on the board
+3V3: C60.2, C61.2, L2.1, L3.2, R24.1; also elsewhere on the board
+5V: C1.2, C4.1, C5.2, C29.2, C58.2, C59.2, FB1.1, L1.1, R1.1, R2.1, R3.1, R7.1, R18.1, R23.1, U2.8 (PVIN), U3.8 (Vin), U4.8 (V+), U8.8 (PVIN); also elsewhere on the board
+12V: C8.2, R5.2, U3.2 (Vout); also elsewhere on the board
-5V: C10.2, U4.5 (VOUT); also elsewhere on the board
GND: C1.1, C4.2, C5.1, C7.2, C8.1, C10.1, C25.2, C26.2, C29.1, C57.1, C58.1, C59.1, C61.1, C62.1, C64.1, D2.1 (K), H1.1, H2.1, H3.1, H4.1, R6.2, R14.2, R25.2, U2.1 (PGND), U2.3 (GND), U2.9 (GND), U3.4 (GND), U4.3 (GND), U8.1 (PGND), U8.3 (GND), U8.9 (GND); also elsewhere on the board
unnamed: D2.2 (A), R7.2
unnamed: C62.2, R1.2, U2.5 (EN), U2.7 (VCC)
unnamed: C63.1, R13.2, R14.1, U2.4 (FB)
unnamed: R2.2, U2.6 (PG)
unnamed: L4.1, U2.2 (SW)
unnamed: C6.1, U3.1 (BST)
unnamed: R3.2, U3.7 (EN)
unnamed: R5.1, R6.1, U3.5 (FB)
unnamed: C6.2, L1.2, U3.3 (SW)
unnamed: C7.1, U3.6 (Vcc)
unnamed: C9.1, U4.2 (CAP+)
unnamed: C9.2, U4.4 (CAP-)
unnamed: C57.2, R18.2, U8.5 (EN), U8.7 (VCC)
unnamed: C60.1, R24.2, R25.1, U8.4 (FB)
unnamed: R23.2, U8.6 (PG)
unnamed: L3.1, U8.2 (SW)
VBUS: FB1.2; also elsewhere on the board

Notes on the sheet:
12V
-5V
3.3VA
3V3
1V2
Mounting holes

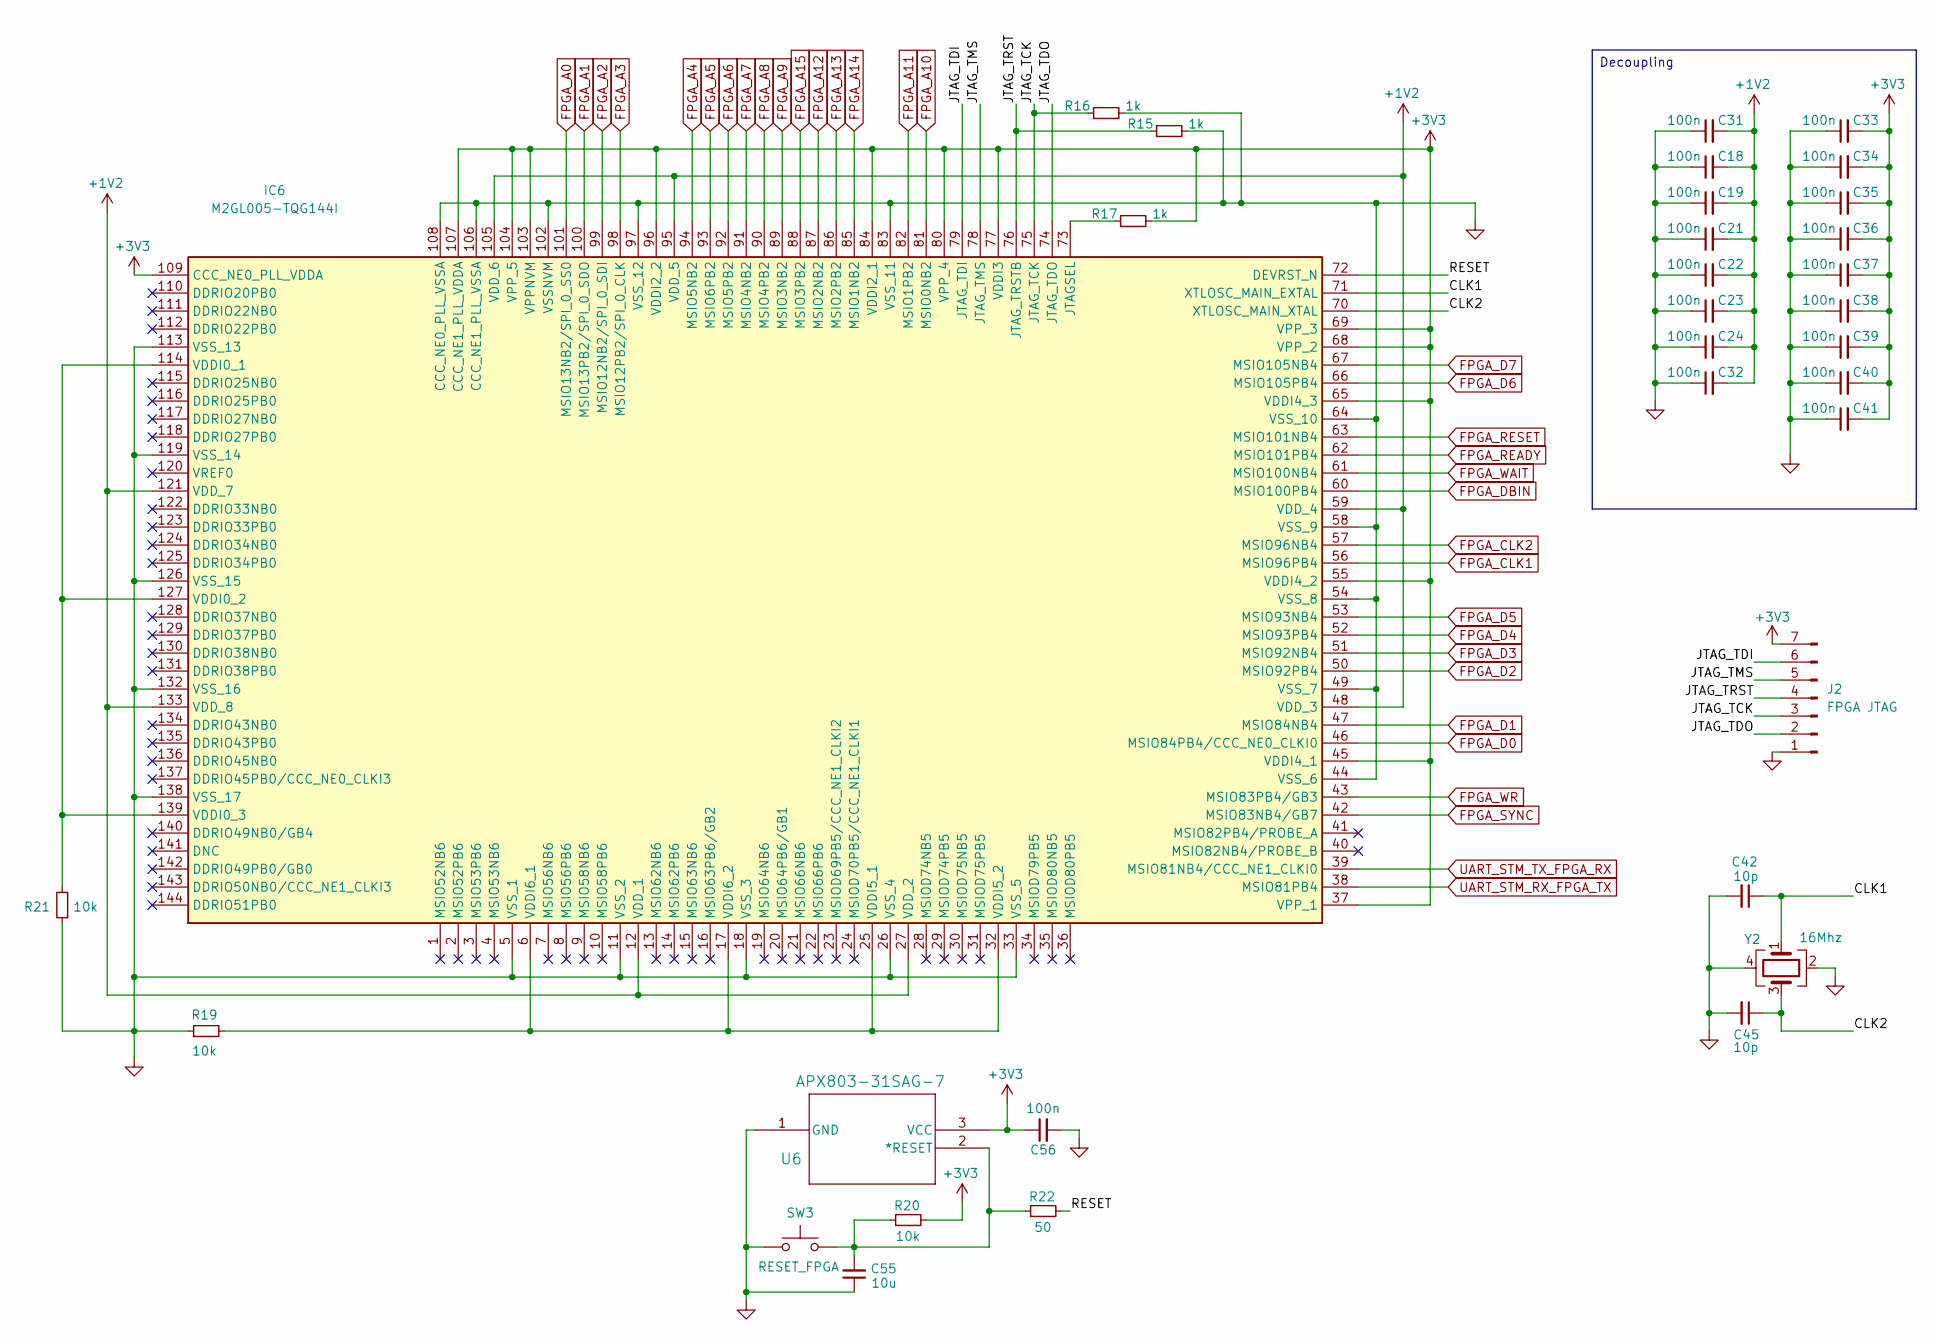
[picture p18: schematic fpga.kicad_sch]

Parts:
C18, C19, C21, C22, C23, C24, C31, C32, C33, C34, C35, C36, C37, C38, C39, C40, C41, C56: 100n; C_0805_2012Metric_Pad1.18x1.45mm_HandSolder; Mouser Part Number 187-CL21B104KBCNNND
C42, C45: 10p; C_0402_1005Metric_Pad0.74x0.62mm_HandSolder; Mouser Part Number 603-CC402JRNPO8BN100
C55: 10u; C_0805_2012Metric_Pad1.18x1.45mm_HandSolder; Mouser Part Number 187-CL21A106KAYNNNF
IC6: M2GL005-TQG144I; QFP50P2200X2200X160-144N; Mouser Part Number 494-M2GL005-TQG144I
J2: FPGA JTAG; PinHeader_1x07_P2.54mm_Vertical; Mouser Part Number 649-1012937990701BLF
R15, R16, R17: 1k; R_0805_2012Metric_Pad1.20x1.40mm_HandSolder; Mouser Part Number 603-RT0805FRE071KL
R19, R20, R21: 10k; R_0805_2012Metric_Pad1.20x1.40mm_HandSolder; Mouser Part Number 603-RT0805DRD0710KL
R22: 50; R_0603_1608Metric_Pad0.98x0.95mm_HandSolder; Mouser Part Number 603-RT0603BRE0750RL
SW3: RESET_FPGA; 435451019820; Mouser Part Number 710-435451019820
U6: APX803-31SAG-7; SOT-23-3; Mouser Part Number 621-APX803-31SAG-7
Y2: 16Mhz; Crystal_SMD_2016-4Pin_2.0x1.6mm; Mouser Part Number 81-XRCGB16M000FXN02R

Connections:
+1V2: C18.2, C19.2, C21.2, C22.2, C23.2, C24.2, C31.2, C32.2, IC6.12 (VDD_1), IC6.27 (VDD_2), IC6.48 (VDD_3), IC6.59 (VDD_4), IC6.95 (VDD_5), IC6.105 (VDD_6), IC6.121 (VDD_7), IC6.133 (VDD_8); also elsewhere on the board
+3V3: C33.2, C34.2, C35.2, C36.2, C37.2, C38.2, C39.2, C40.2, C41.2, C56.1, IC6.37 (VPP_1), IC6.45 (VDDI4_1), IC6.55 (VDDI4_2), IC6.65 (VDDI4_3), IC6.68 (VPP_2), IC6.69 (VPP_3), IC6.77 (VDDI3), IC6.80 (VPP_4), IC6.84 (VDDI2_1), IC6.96 (VDDI2_2), IC6.103 (VPPNVM), IC6.104 (VPP_5), IC6.107 (CCC_NE1_PLL_VDDA), IC6.109 (CCC_NE0_PLL_VDDA), J2.7, R17.2, R20.2, U6.3 (VCC); also elsewhere on the board
/FPGA/CLK1: C42.1, IC6.71 (XTLOSC_MAIN_EXTAL), Y2.1
/FPGA/CLK2: C45.1, IC6.70 (XTLOSC_MAIN_XTAL), Y2.3
/FPGA/JTAG_TCK: IC6.75 (JTAG_TCK), J2.3, R16.1
/FPGA/JTAG_TDI: IC6.79 (JTAG_TDI), J2.6
/FPGA/JTAG_TDO: IC6.74 (JTAG_TDO), J2.2
/FPGA/JTAG_TMS: IC6.78 (JTAG_TMS), J2.5
/FPGA/JTAG_TRST: IC6.76 (JTAG_TRSTB), J2.4, R15.1
/FPGA/RESET: IC6.72 (DEVRST_N), R22.2
FPGA_A0: IC6.101 (MSIO13NB2/SPI_0_SS0); also elsewhere on the board
FPGA_A1: IC6.100 (MSIO13PB2/SPI_0_SDO); also elsewhere on the board
FPGA_A2: IC6.99 (MSIO12NB2/SPI_0_SDI); also elsewhere on the board
FPGA_A3: IC6.98 (MSIO12PB2/SPI_0_CLK); also elsewhere on the board
FPGA_A4: IC6.94 (MSIO5NB2); also elsewhere on the board
FPGA_A5: IC6.93 (MSIO6PB2); also elsewhere on the board
FPGA_A6: IC6.92 (MSIO5PB2); also elsewhere on the board
FPGA_A7: IC6.91 (MSIO4NB2); also elsewhere on the board
FPGA_A8: IC6.90 (MSIO4PB2); also elsewhere on the board
FPGA_A9: IC6.89 (MSIO3NB2); also elsewhere on the board
FPGA_A10: IC6.81 (MSIO0NB2); also elsewhere on the board
FPGA_A11: IC6.82 (MSIO1PB2); also elsewhere on the board
FPGA_A12: IC6.87 (MSIO2NB2); also elsewhere on the board
FPGA_A13: IC6.86 (MSIO2PB2); also elsewhere on the board
FPGA_A14: IC6.85 (MSIO1NB2); also elsewhere on the board
FPGA_A15: IC6.88 (MSIO3PB2); also elsewhere on the board
FPGA_CLK1: IC6.56 (MSIO96PB4); also elsewhere on the board
FPGA_CLK2: IC6.57 (MSIO96NB4); also elsewhere on the board
FPGA_D0: IC6.46 (MSIO84PB4/CCC_NE0_CLKI0); also elsewhere on the board
FPGA_D1: IC6.47 (MSIO84NB4); also elsewhere on the board
FPGA_D2: IC6.50 (MSIO92PB4); also elsewhere on the board
FPGA_D3: IC6.51 (MSIO92NB4); also elsewhere on the board
FPGA_D4: IC6.52 (MSIO93PB4); also elsewhere on the board
FPGA_D5: IC6.53 (MSIO93NB4); also elsewhere on the board
FPGA_D6: IC6.66 (MSIO105PB4); also elsewhere on the board
FPGA_D7: IC6.67 (MSIO105NB4); also elsewhere on the board
FPGA_DBIN: IC6.60 (MSIO100PB4); also elsewhere on the board
FPGA_READY: IC6.62 (MSIO101PB4); also elsewhere on the board
FPGA_RESET: IC6.63 (MSIO101NB4); also elsewhere on the board
FPGA_SYNC: IC6.42 (MSIO83NB4/GB7); also elsewhere on the board
FPGA_WAIT: IC6.61 (MSIO100NB4); also elsewhere on the board
FPGA_WR: IC6.43 (MSIO83PB4/GB3); also elsewhere on the board
GND: C18.1, C19.1, C21.1, C22.1, C23.1, C24.1, C31.1, C32.1, C33.1, C34.1, C35.1, C36.1, C37.1, C38.1, C39.1, C40.1, C41.1, C42.2, C45.2, C55.1, C56.2, IC6.5 (VSS_1), IC6.11 (VSS_2), IC6.18 (VSS_3), IC6.26 (VSS_4), IC6.33 (VSS_5), IC6.44 (VSS_6), IC6.49 (VSS_7), IC6.54 (VSS_8), IC6.58 (VSS_9), IC6.64 (VSS_10), IC6.83 (VSS_11), IC6.97 (VSS_12), IC6.102 (VSSNVM), IC6.106 (CCC_NE1_PLL_VSSA), IC6.108 (CCC_NE0_PLL_VSSA), IC6.113 (VSS_13), IC6.119 (VSS_14), IC6.126 (VSS_15), IC6.132 (VSS_16), IC6.138 (VSS_17), J2.1, R15.2, R16.2, R19.1, R21.1, SW3.1, U6.1 (GND), Y2.2, Y2.4; also elsewhere on the board
unnamed: IC6.73 (JTAGSEL), R17.1
unnamed: IC6.114 (VDDI0_1), IC6.127 (VDDI0_2), IC6.139 (VDDI0_3), R21.2
unnamed: IC6.6 (VDDI6_1), IC6.17 (VDDI6_2), IC6.25 (VDDI5_1), IC6.32 (VDDI5_2), R19.2
unnamed: C55.2, R20.1, R22.1, SW3.2, U6.2 (*RESET)
UART_STM_RX_FPGA_TX: IC6.38 (MSIO81PB4); also elsewhere on the board
UART_STM_TX_FPGA_RX: IC6.39 (MSIO81NB4/CCC_NE1_CLKI0); also elsewhere on the board

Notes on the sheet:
Decoupling

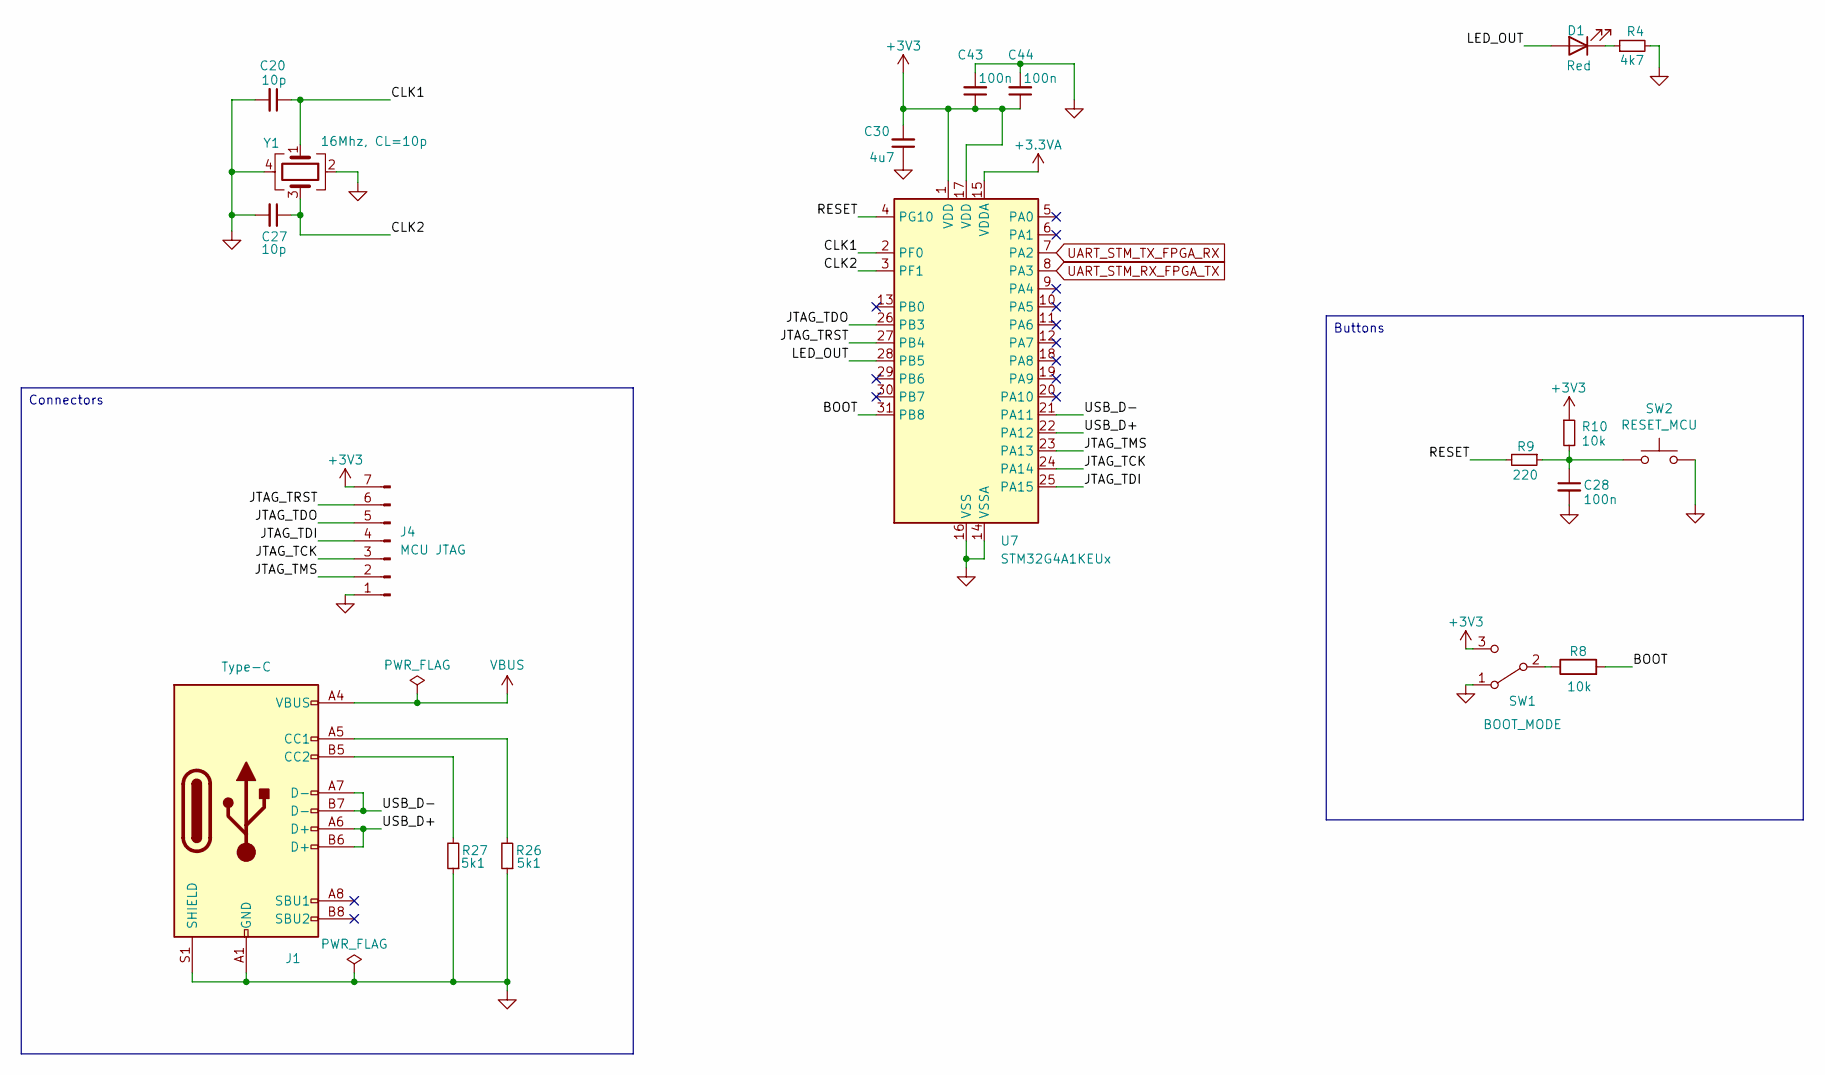
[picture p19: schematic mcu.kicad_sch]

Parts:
C20, C27: 10p; C_0805_2012Metric_Pad1.18x1.45mm_HandSolder; Mouser Part Number 710-885012007051
C28, C43, C44: 100n; C_0805_2012Metric_Pad1.18x1.45mm_HandSolder; Mouser Part Number 187-CL21B104KBCNNND
C30: 4u7; C_0805_2012Metric_Pad1.18x1.45mm_HandSolder; Mouser Part Number 187-CL21A475KAQNNNE
D1: Red; LED_0805_2012Metric_Pad1.15x1.40mm_HandSolder; Mouser Part Number 710-150080RS75000
J1: Type-C; USB_C_Receptacle_JAE_DX07S016JA1R1500; Mouser Part Number 656-DX07S016JA1R1500
J4: MCU JTAG; PinHeader_1x07_P2.54mm_Vertical; Mouser Part Number 649-1012937990701BLF
R4: 4k7; R_0805_2012Metric_Pad1.20x1.40mm_HandSolder; Mouser Part Number 603-RT0805FRE134K7L
R8, R10: 10k; R_0805_2012Metric_Pad1.20x1.40mm_HandSolder; Mouser Part Number 603-RT0805DRD0710KL
R9: 220; R_0805_2012Metric_Pad1.20x1.40mm_HandSolder; Mouser Part Number 603-RT0805FRE07220RL
R26, R27: 5k1; R_0805_2012Metric_Pad1.20x1.40mm_HandSolder; Mouser Part Number 603-RT0805FRE075K1L
SW1: BOOT_MODE; SLW1215865AD; Mouser Part Number SLW-121586-5A-D
SW2: RESET_MCU; 435451019820; Mouser Part Number 710-435451019820
U7: STM32G4A1KEUx; QFN-32-1EP_5x5mm_P0.5mm_EP3.45x3.45mm; Mouser Part Number 511-STM32G4A1KEU6
Y1: 16Mhz, CL=10p; XTAL_ECS-160-10-36-CKM-TR3; Mouser Part Number 520-160-10-36CKM-TR3

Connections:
+3.3VA: U7.15 (VDDA); also elsewhere on the board
+3V3: C30.2, C43.1, C44.1, J4.7, R10.1, SW1.3 (C), U7.1 (VDD), U7.17 (VDD); also elsewhere on the board
/MCU/BOOT: R8.2, U7.31 (PB8)
/MCU/CLK1: C20.1, U7.2 (PF0), Y1.1
/MCU/CLK2: C27.1, U7.3 (PF1), Y1.3
/MCU/JTAG_TCK: J4.3, U7.24 (PA14)
/MCU/JTAG_TDI: J4.4, U7.25 (PA15)
/MCU/JTAG_TDO: J4.5, U7.26 (PB3)
/MCU/JTAG_TMS: J4.2, U7.23 (PA13)
/MCU/JTAG_TRST: J4.6, U7.27 (PB4)
/MCU/LED_OUT: D1.2 (A), U7.28 (PB5)
/MCU/RESET: R9.2, U7.4 (PG10)
/MCU/USB_D+: J1.A6 (D+), J1.B6 (D+), U7.22 (PA12)
/MCU/USB_D-: J1.A7 (D-), J1.B7 (D-), U7.21 (PA11)
GND: C20.2, C27.2, C28.2, C30.1, C43.2, C44.2, J1.A1 (GND), J1.A12 (GND), J1.B1 (GND), J1.B12 (GND), J1.S1 (SHIELD), J4.1, R4.2, R26.1, R27.1, SW1.1 (A), SW2.2, U7.14 (VSSA), U7.16 (VSS), U7.32 (VSS), U7.33 (VSS), Y1.2, Y1.4; also elsewhere on the board
unnamed: C28.1, R9.1, R10.2, SW2.1
unnamed: D1.1 (K), R4.1
unnamed: J1.A5 (CC1), R26.2
unnamed: J1.B5 (CC2), R27.2
unnamed: R8.1, SW1.2 (B)
UART_STM_RX_FPGA_TX: U7.8 (PA3); also elsewhere on the board
UART_STM_TX_FPGA_RX: U7.7 (PA2); also elsewhere on the board
VBUS: J1.A4 (VBUS), J1.A9 (VBUS), J1.B4 (VBUS), J1.B9 (VBUS); also elsewhere on the board

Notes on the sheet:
Buttons
Connectors

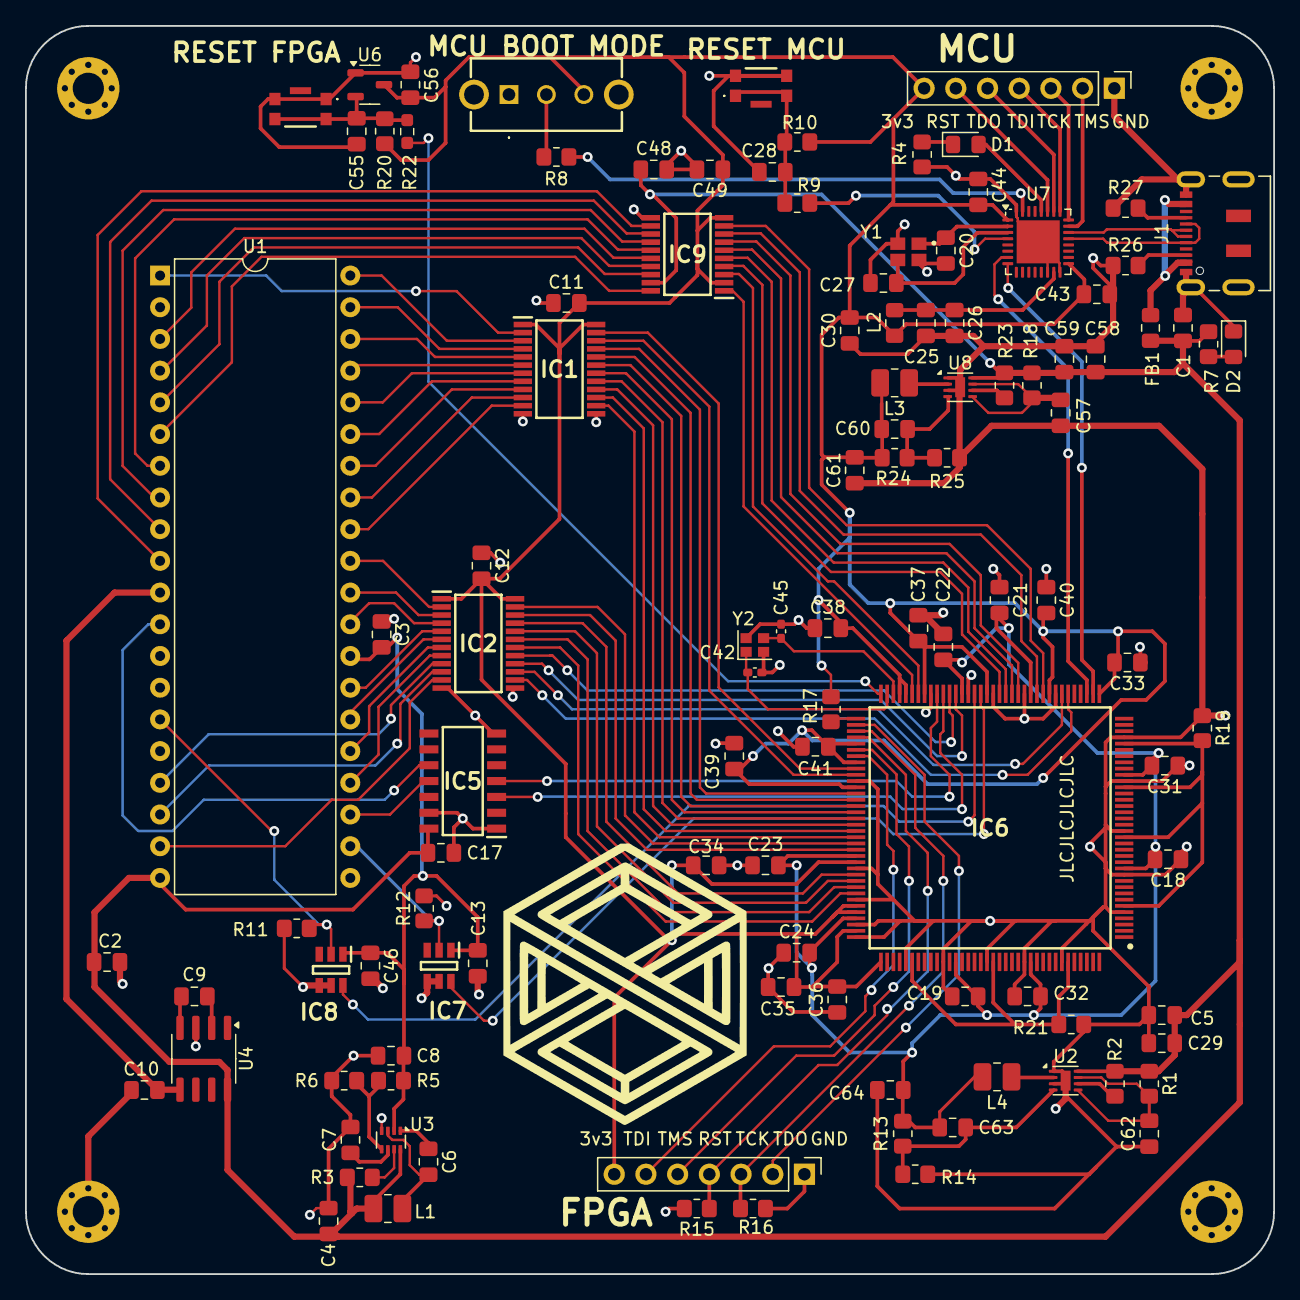
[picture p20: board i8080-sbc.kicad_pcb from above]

Board: 2 copper layers, 100.0 x 100.0 mm, 115 parts (0 on the bottom side), 119 nets.

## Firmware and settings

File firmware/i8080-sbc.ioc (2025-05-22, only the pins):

Mcu.UserName=STM32G4A1KEUx
PA11.Signal=USB_DM
PA12.Signal=USB_DP
PA13.Signal=SYS_JTMS-SWDIO
PA14.Signal=SYS_JTCK-SWCLK
PA15.Signal=SYS_JTDI
PA2.Signal=USART2_TX
PA3.Signal=USART2_RX
PB3.Signal=SYS_JTDO-SWO
PB4.Signal=SYS_JTRST
PB5.GPIO_Label=LED_OUT
PB5.Signal=GPIO_Output

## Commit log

2025-05-22 BOM formatting
2025-05-24 fix silkscreen for MCU JTAG pins
    [i8080-sbc.kicad_pcb]
